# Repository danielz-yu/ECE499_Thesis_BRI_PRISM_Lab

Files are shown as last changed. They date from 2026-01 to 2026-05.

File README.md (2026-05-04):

# ECE499Y Thesis

**Development and Characterization of Textile-Electrode Electroencephalogram Systems for Brain-Computer Interfaces**

The objective of this thesis is to advance the development of a wearable electroencephalography (EEG) system using textile-based electrodes for signal acquisition over hair-covered regions and regions where the skin is exposed directly. The project encompasses both hardware and software development, with a focus on prototyping pre-amplifier circuits for textile electrodes and designing computational methods for processing these recorded textile-based EEG signals.

A pre-amplifier circuit will be prototyped and tested to specifically improve signal acquisition from textile electrodes. Afterwards, digital signal processing methods will be implemented to filter and enhance textile-based EEG signals. Models will be developed to mitigate noise, improve signal-to-noise ratio, and optimize classification performance in brain-computer interface (BCI) applications. The combined hardware and software system’s performance will be characterized and benchmarked against gold-standard clinical EEG electrodes in both simple experimental paradigms and established BCI tasks.

This study aims to demonstrate the technical feasibility of textile-based EEG for wearable BCI applications and its research outcomes are expected to contribute both to academic knowledge and to potential commercialization efforts in collaboration with industry partners. Findings will support the preparation of a publication detailing textile electrode validation, EEG signal amplifier design, and software-based signal filtering, with future applications extending toward wearable BCI systems and clinical use cases.

#

**Research:**
- **Thesis Title:** Development and Characterization of Textile-Electrode Electroencephalogram Systems for 
Brain-Computer Interfaces
- **Supervisors:** Dr. Tom Chau, Dr. Paul Yoo
- **Affiliations:** Bloorview Research Institute, Holland Bloorview Kids Rehabilitation Hospital; Department of Electrical & Computer Engineering, University of Toronto; Institute of Biomedical Engineering, University of Toronto

**Deliverables:**
- ✏️ [Proposal](https://github.com/danielz-yu/ECE499_Thesis_BRI_PRISM_Lab/blob/main/ece499_deliverables/proposal/ECE499%20Thesis%20Proposal%20%7C%20Daniel%20Yu.pdf)
- 📚 [Interim Report](https://github.com/danielz-yu/ECE499_Thesis_BRI_PRISM_Lab/blob/main/ece499_deliverables/interim_report/ECE499%20Interim%20Report%20%7C%20Daniel%20Yu.pdf)
- 📔 [Thesis](https://github.com/danielz-yu/ECE499_Thesis_BRI_PRISM_Lab/blob/main/ece499_deliverables/final_thesis/ECE499%20Final%20Thesis%20Report%20%7C%20Daniel%20Yu.pdf)

#
<br>

<div align="center">
    <a href="https://hollandbloorview.ca/research-education/bloorview-research-institute">
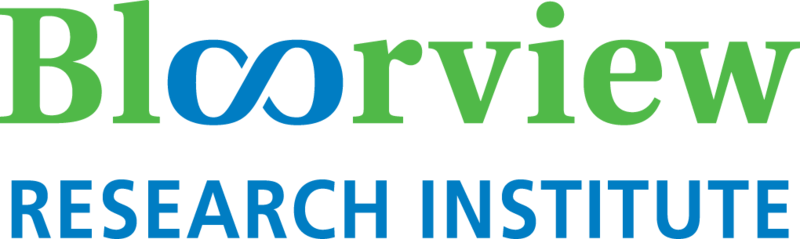
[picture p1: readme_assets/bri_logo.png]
Bloorview Research Institute
        
    </a>
</div>

<br>
<br>
<br>

<div align="center">
    <a href="https://hollandbloorview.ca/">
        Holland Blooriew Kids Rehabilitation Hospital
    </a>
</div>

<br>
<br>

<p align="center">
  <a href="https://www.ece.utoronto.ca/">Department of Electrical & Computer Engineering</a>
  &nbsp;&nbsp;&nbsp;&nbsp;
  <a href="https://bme.utoronto.ca/">Institude of Biomedical Engineering</a>
</p>

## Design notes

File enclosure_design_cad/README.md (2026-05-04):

## Enclosure Design CAD

This folder contains the source and export files used for the active electrode enclosure.

- `3D_printing/` — print-preparation files:
	- `.3mf` file: Editable 3D slicer file. This can be modified when changing which parts to print or print settings before slicing.
	- `.gcode` file: Pre-sliced printer instructions prepared with my printer settings (PLA, Bambu Lab A1).
- `fusion360/` — Native Autodesk Fusion 360 part files:
	- `.f3d` files: Contains full editable single-part designs (retains design history and all features).
	- `.f3z` files: Fusion 360 assemblies (contain multiple parts and references). Assemblies require their referenced part files to open correctly.
- `renders/` — Rendered images showing what the assembled enclosure should look like.
- `step/` — STEP exports for CAD exchange. STEP is more interoperable but still loses parametric feature history compared to native files.
- `stl/` — Exported meshes for 3D printing or simulation. Note: STL is a triangulated mesh and loses feature/history/parametric data from the native CAD.

## Other Notes

- Use the native Fusion 360 `.f3d` files to make design changes or extract precise dimensions. 
- Use STEP only for exchange with other CAD packages or if the CAD software does not import native Fusion 360 files.
- Use STL for quick printing or prototyping, but be aware it is a mesh-only format.
- The `.3mf` in `3D_printing/` is the recommended starting point for preparing prints as it contains part placement and custom print settings.
- The included `.gcode` was sliced for a Bambu Lab A1 with PLA using my printer profile. If you use a different printer or material, re-slice from the `.3mf` (or from an STL exported from the native part) to ensure proper temperatures, speeds, and bed/filament settings.

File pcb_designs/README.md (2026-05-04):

# Printed Circuit Boards (PCB)

This folder contains the KiCad PCB designs for the active electrode prototypes, including custom KiCad component libraries, board schematics and layouts, and production files.

## Custom KiCad Libraries

The `custom_KiCad_components/` folder contains custom-designed symbols, footprints, and 3D models for components used in these PCB designs.

### Adding Custom Libraries to KiCad:

#### 1. Symbol Libraries
Open KiCad Symbol Editor → Preferences → Manage Symbol Libraries → Folder Icon (bottom left corner) → Select the symbols folder at:
```
/{USER_PATH}/custom_KiCad_components/ECE499_Thesis.kicad_sym
```

#### 2. Footprint Libraries
Open KiCad Footprint Editor → Preferences → Manage Footprint Libraries → Folder Icon (bottom left corner) → Select the .pretty folder at:
```
/{USER_PATH}/custom_KiCad_components/ECE499_Thesis.pretty/
```

#### 3. 3D Models
3D models are located in:
```
/{USER_PATH}/custom_KiCad_components/ECE499_Thesis.3dshapes/
```
3D models can be copied to your local computer's KiCad application folder at the `3dmodels` folder and synced to each component manually.

### Important Notes:
- In both the Symbol and Footprint Editors, ensure that custom libraries have **"Active"** and **"Visible"** checkmarks enabled.
  - These are set by default but may need verification if the libraries do not appear.
  - Refresh the editors after enabling to load the new custom components.

## Folder Structure

### `old_designs/`
Contains old, incorrect KiCad PCB designs kept for historical reference only. **Do not use these for production or future work.**

### `OpenEEG-J_Foltynsky/` and `OpenEEG-J_Hansmann/`
Two reference designs based on the [OpenEEG project](https://users.dcc.uchile.cl/~peortega/ae/):
- **J. Foltynsky Design**: OpenEEG variant by Jarek Foltynsky
- **J. Hansmann Design**: OpenEEG variant by Joerg Hansmann

Each folder contains:
- `.kicad_sch` 	— Schematic file
- `.kicad_pcb` 	— PCB layout file
- `.kicad_pro` 	— KiCad project file (main file) 
- `.step` 		— 3D STEP model of the board
- `-backups/` 	— Backup folder for version control
- `production/` — Generated production files (see explanation below)

#### Production Folder
The `production/` subfolder contains files generated using the **KiCad Fabrication Toolkit** (available natively in KiCad Content Manager):
- **Gerber Files** — A zipped file containing all PCB layers and drill holes for board fabrication
- **BOM (Bill of Materials)** — A CSV list of all active and passive components required for direct manufacturer PCB assembly
- **Positions CSV** — XY coordinates and rotation angles of all components required for direct manufacturer PCB assembly

## JLCPCB Ordering Details

These PCB designs are configured for ordering from JLCPCB. Use the following settings:

### Recommended Settings
- **URL**: https://jlcpcb.com/
- **Deburring**: No
  - Deburring is typically only available for very small boards
  - Use "No" for prototype boards (deburring adds time)
  - For final production boards, enable deburring to polish the edges

### PCB Assembly
- **Make sure to double-check the footprint for all components** before submitting.
- **Verify integrated circuit (IC) pin alignment** — Ensure all ICs are oriented with the correct first pin position matching the schematic.

### Upload Files
- Upload the `.zip` Gerber file directly from the `production/` folder
- Upload the BOM and positions CSV for assembly services if needed
- Review and confirm component placement on JLCPCB's interactive preview before finalizing

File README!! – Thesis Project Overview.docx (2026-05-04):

Development and Characterization of Textile-Electrode Electroencephalogram Systems for Brain-Computer Interfaces

The objective of this thesis is to advance the development of a wearable electroencephalography (EEG) system using textile-based electrodes for signal acquisition over hair-covered regions and regions where the skin is exposed directly. The project encompasses both hardware and software development, with a focus on prototyping pre-amplifier circuits for textile electrodes and designing computational methods for processing these recorded textile-based EEG signals.

A pre-amplifier circuit will be prototyped and tested to specifically improve signal acquisition from textile electrodes. Afterwards, digital signal processing methods will be implemented to filter and enhance textile-based EEG signals. Models will be developed to mitigate noise, improve signal-to-noise ratio, and optimize classification performance in brain-computer interface (BCI) applications. The combined hardware and software system’s performance will be characterized and benchmarked against gold-standard clinical EEG electrodes in both simple experimental paradigms and established BCI tasks.

This study aims to demonstrate the technical feasibility of textile-based EEG for wearable BCI applications and its research outcomes are expected to contribute both to academic knowledge and to potential commercialization efforts in collaboration with industry partners. Findings will support the preparation of a publication detailing textile electrode validation, EEG signal amplifier design, and software-based signal filtering, with future applications extending toward wearable BCI systems and clinical use cases.

Folder Structure

- Code/
  - Contains a Python script for XDF processing and plotting, along with coding requirements.
- Data/
  - Recorded raw EEG datasets for analysis.
  - Contains .xdf`sessions and organized by different recording dates and devices.
- Documents/
  - Includes thesis documents and presentation assets.
- Enclosure Design/
  - Mechanical design files for the printed circuit board enclosure.
  - Contains Autodesk Fusion 360 files, various computer-aided design exports, model renders, and 3D printing code.
- Papers/
  - Reference literature and research papers relevant to the textile project.
- Printed Circuit Boards/
  - Hardware design files and manufacturing assets.
  - Contains KiCad projects, custom symbols/footprints/3D models, old design iterations, and production files.
- Results/
  - Plot generated from the XDF analysis script.
  - Organized between testing methodologies for all figures and derived data.

Design Sourcing

Software:

- Mechanical Design
  - Autodesk Fusion 360
  - BambuStudio
- Electrical Design
  - KiCad

Hardware:

- Enclosure Assembly
  - PLA filament printed using a Bambu Lab A1 printer
  - Snap buttons taken from these connectors in the Rapid Prototyping Hub’s electronic cabinet

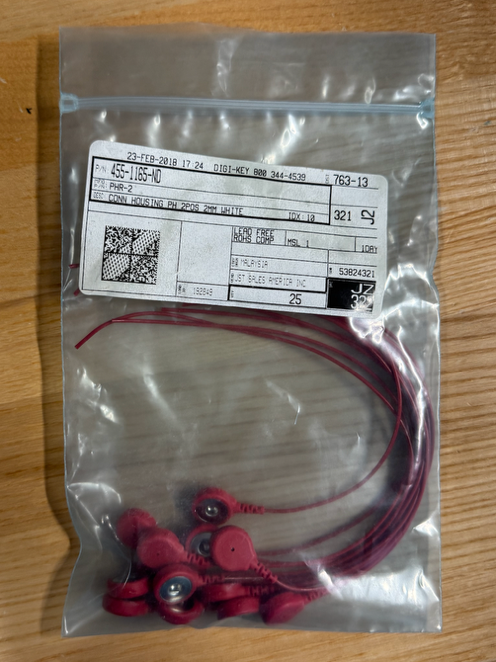
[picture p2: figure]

    - The female snap button needs to be ripped out of this component
- Circuit Testing
  - All electrical components sources from the Rapid Prototyping Hub
    - Specifically used the AD706 operational amplifier
  - Breadboard, oscilloscope, voltmeter, and other testing devices sourced from the Rapid Prototyping Hub
- PCB Design
  - Manufactured using the PCB Assembly option with JLCPCB (https://jlcpcb.com/)
  - Power and signal connections used stranded 32 AWG shielded wires found here:
    - https://www.digikey.ca/en/products/detail/tensility-international-corp/30-01432/13151730
  - Soldering completed at the University of Toronto; can also be completed in the Rapid Prototyping Hub

Contact

- UofT Email: danielz.yu@mail.utoronto.ca
- Personal Email: danielu6776@gmail.com

Feel free to contact me anytime! :)

ECE499Y | ThesisDaniel Yu University of Toronto2025 – 2026

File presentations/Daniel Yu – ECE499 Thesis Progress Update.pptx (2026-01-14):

## ECE499 Thesis Progress Update

Daniel Yu
January 7th, 2026

## Outline

- Problem Statement & Objective
- Methodology
- Preliminary Results
- Next Steps & Timeline

## Problem Statement & Objective

Core Problem:
- To design and validate textile EEG electrodes that can achieve clinically acceptable signal quality while improving usability
Current Limitations:
- Wet EEG systems impractical for pediatric and long-duration use
- Textile and dry electrodes remain insufficiently validated

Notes: Limitations of Pediatric EEG Acquisition
Conventional wet EEG systems are impractical for pediatric and long-duration use due to discomfort from gel, lengthy setup, and sensitivity to motion.
Textile and dry electrodes offer improved wearability, but their signal quality, robustness, and performance over hair remain insufficiently validated.
There is a lack of standardized, repeatable validation frameworks—including anatomically realistic head phantoms—for comparing emerging EEG sensor materials against medical-grade gold standards.
Consequently, the design trade-offs between comfort, manufacturability, and signal fidelity in pediatric EEG systems are not well understood.
Core Problem:
How to design and rigorously validate multichannel pediatric EEG sensors—particularly textile-based electrodes—that achieve clinically acceptable signal quality while improving usability.

Sub-objectives to explore pre-amplifier design

## Methodology

Raised Height (1.1-1.3)
1mm, 2mm, 3mm
Silver Density (2.1-2.3)
1x, 1.5x, 2x
Area Size (3.1-3.3)
0.5cm, 1.0cm, 2.0cm

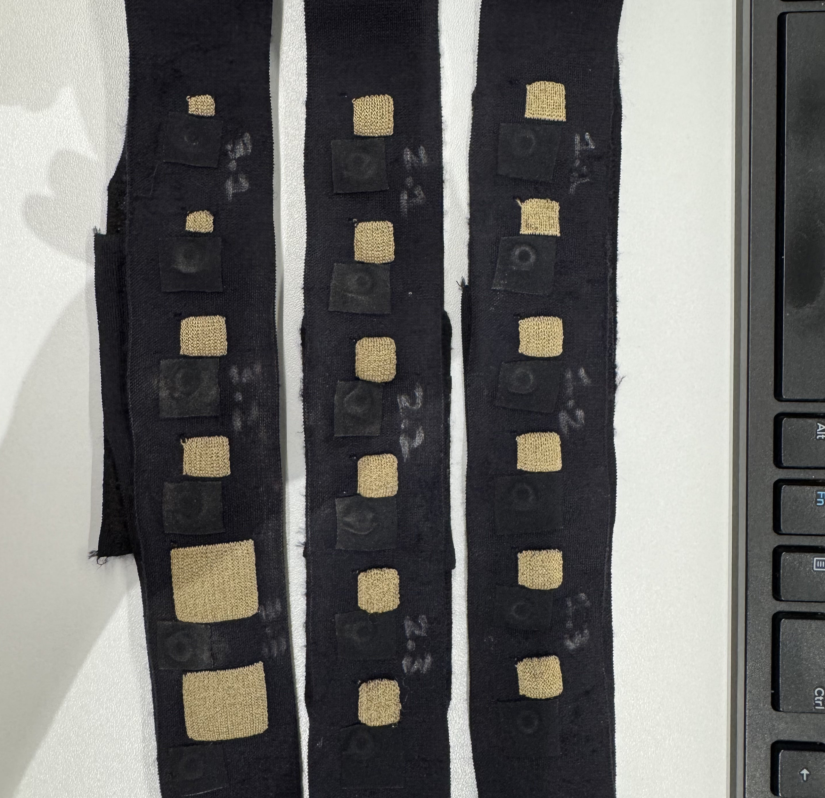
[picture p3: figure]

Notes: - 1.0 --> Raised Height (1x density)
- 1.1: 1 mm
- 1.2: 2 mm
- 1.3: 3 mm
- 2.0 --> Silver Density (2mm height)
- 2.1: least dense (1x)
- 2.2: moderately dense (1.5x)
- 2.3: most dense (2x)
- 3.0 --> Area Size (1x density, 2mm height)
- 3.1: ~0.5 x 0.5 cm
- 3.2: ~1.0 x 1.0 cm
- 3.3: ~2.0 x 2.0 cm
- Notes:
- All pad sizes are approximately 1.0 x 1.0 cm if not specified
- Need more precise quantitative measurables

## Methodology

- Comparison between dry BrainProduct electrodes and textiles electrodes at Fp1 and Fp2 positions
- EEG data acquired using LiveAmp, Lab Recorder, and Mindset

Blink Test:
Movement artifacts
~200 seconds x 10 times
2 seconds per blink
Eyes Open/Closed:
Alpha band
10 seconds open/closed x 10 times

## Preliminary Results

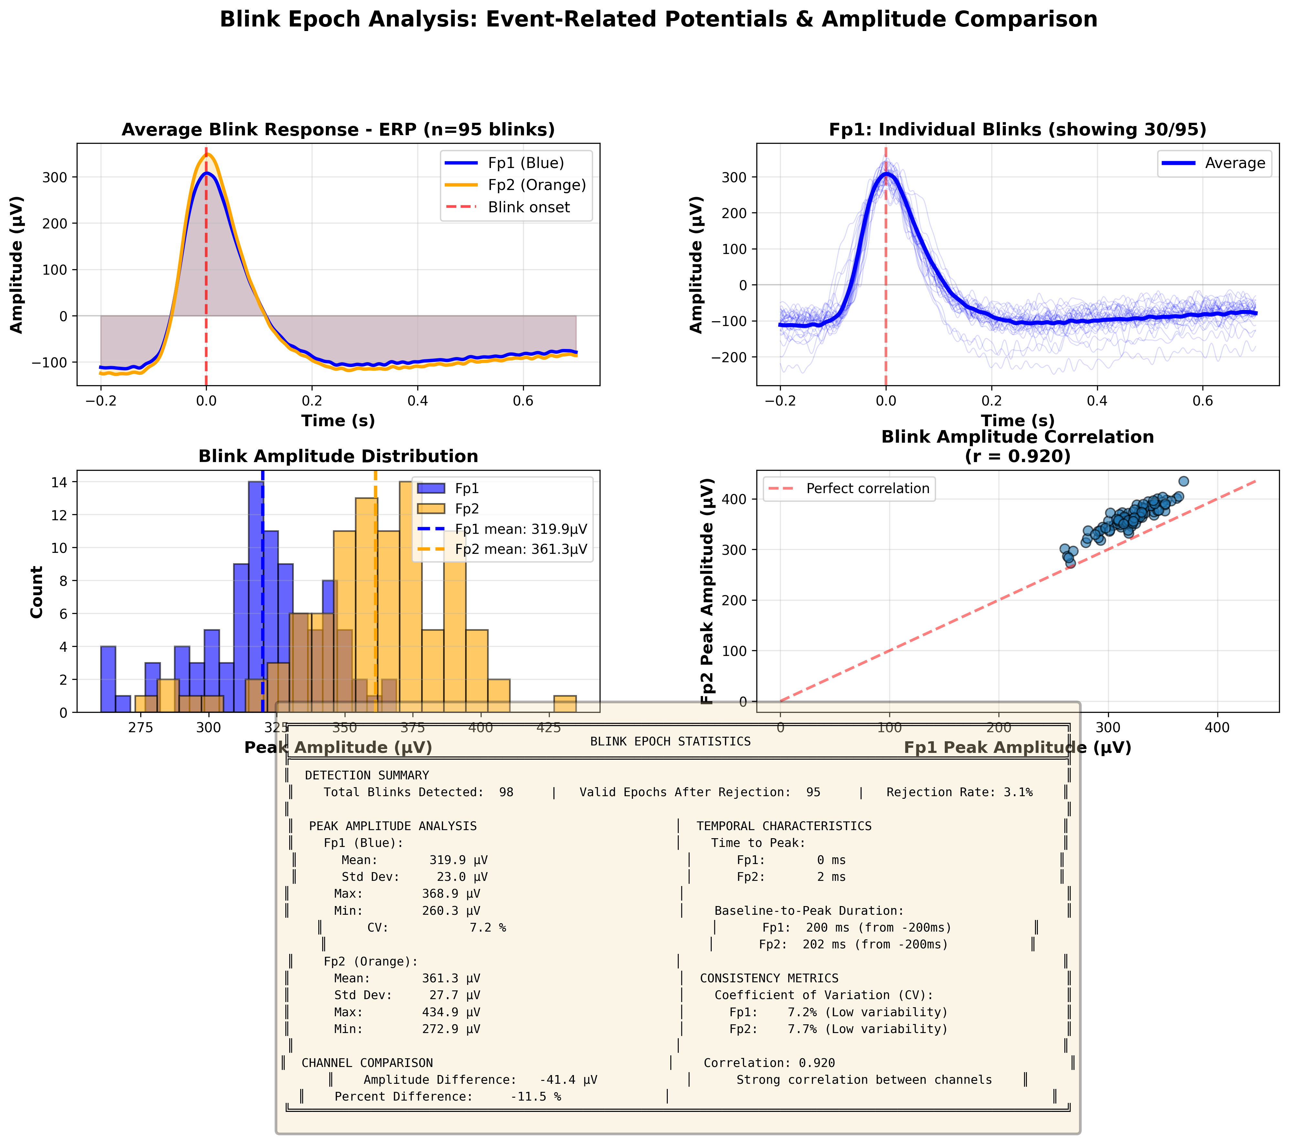
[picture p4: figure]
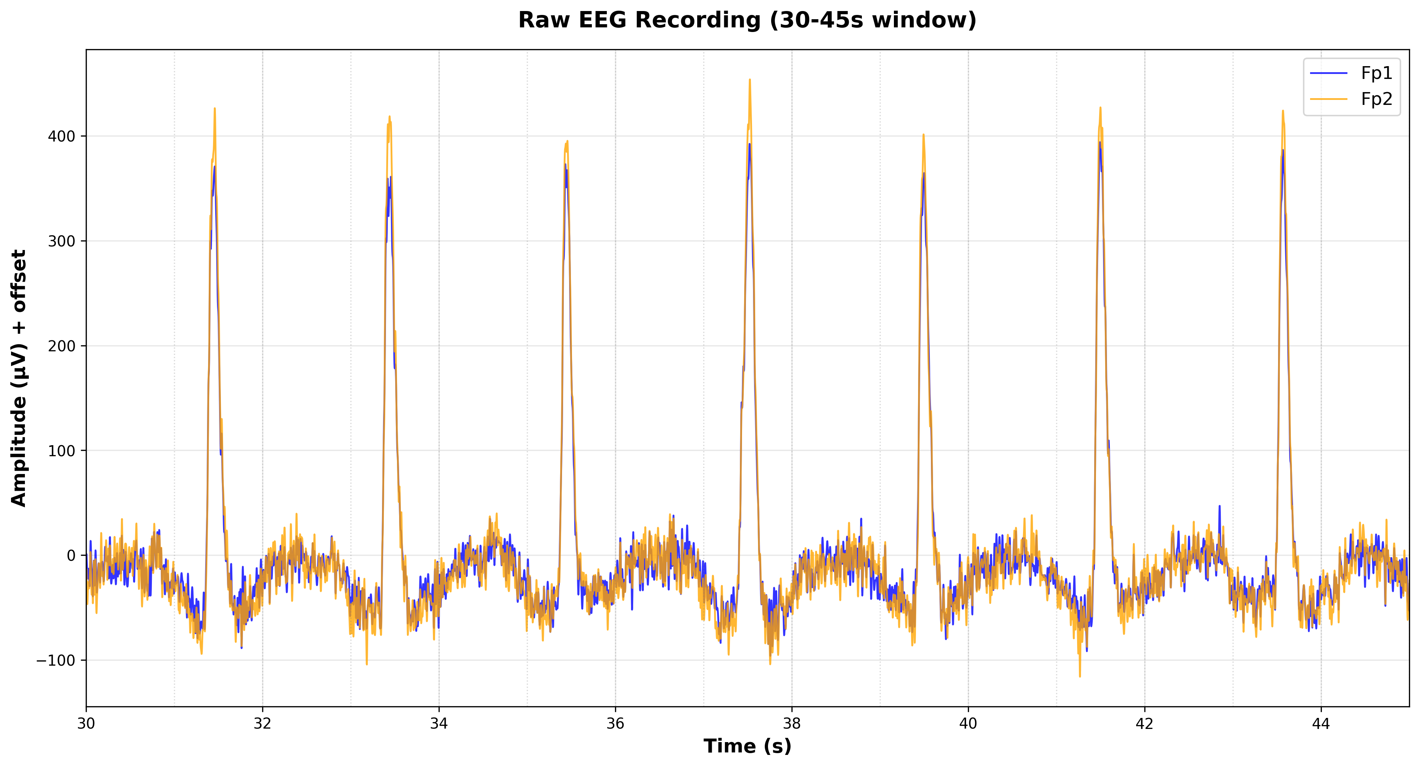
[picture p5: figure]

## Preliminary Results

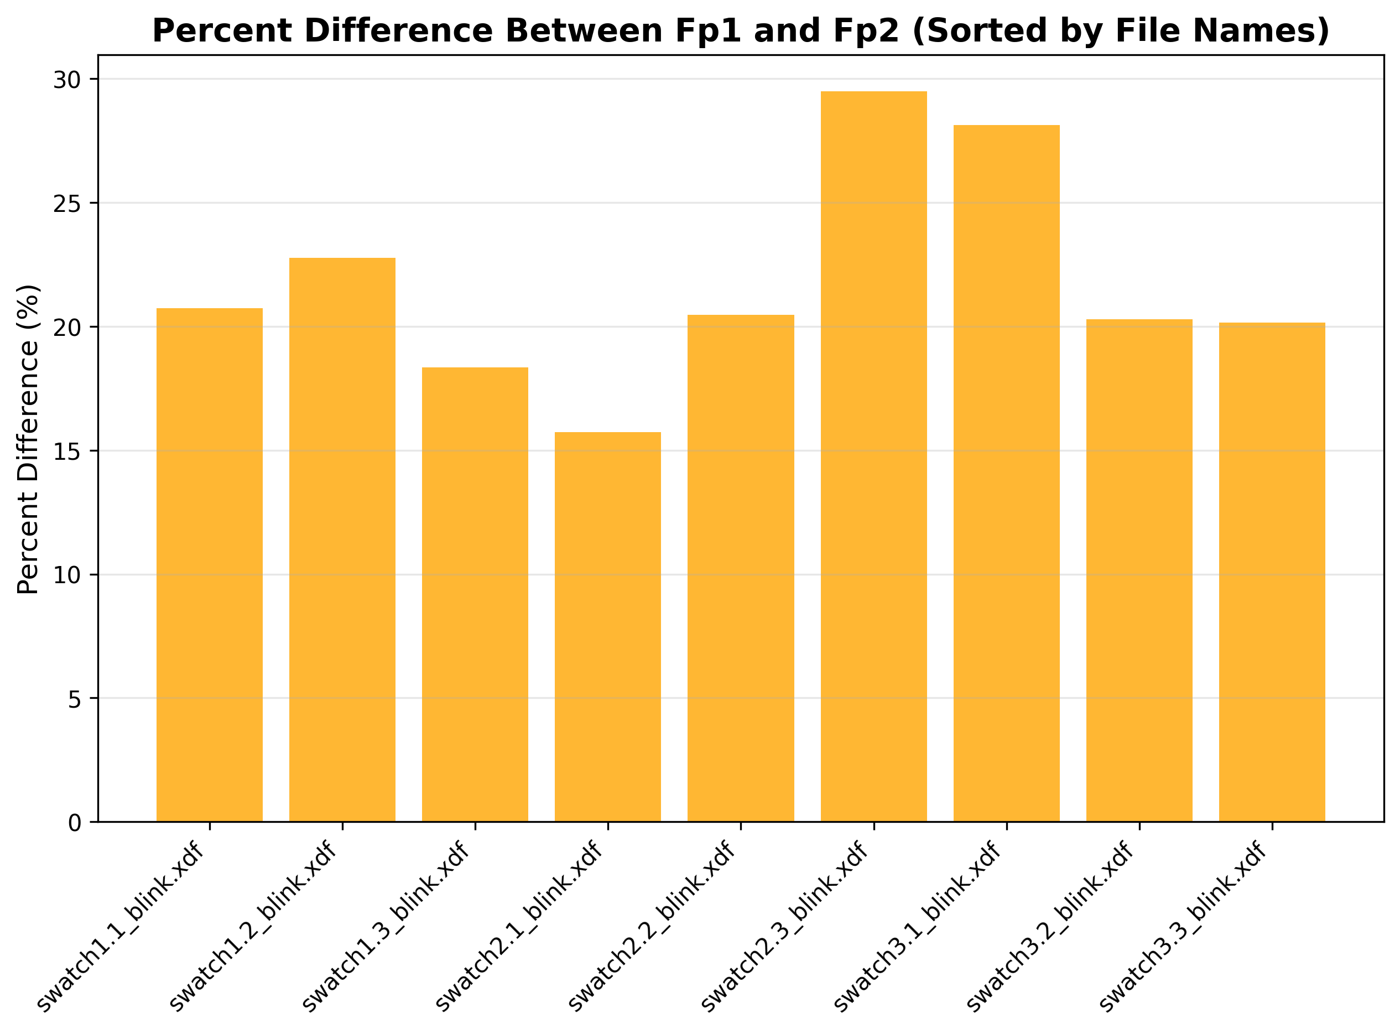
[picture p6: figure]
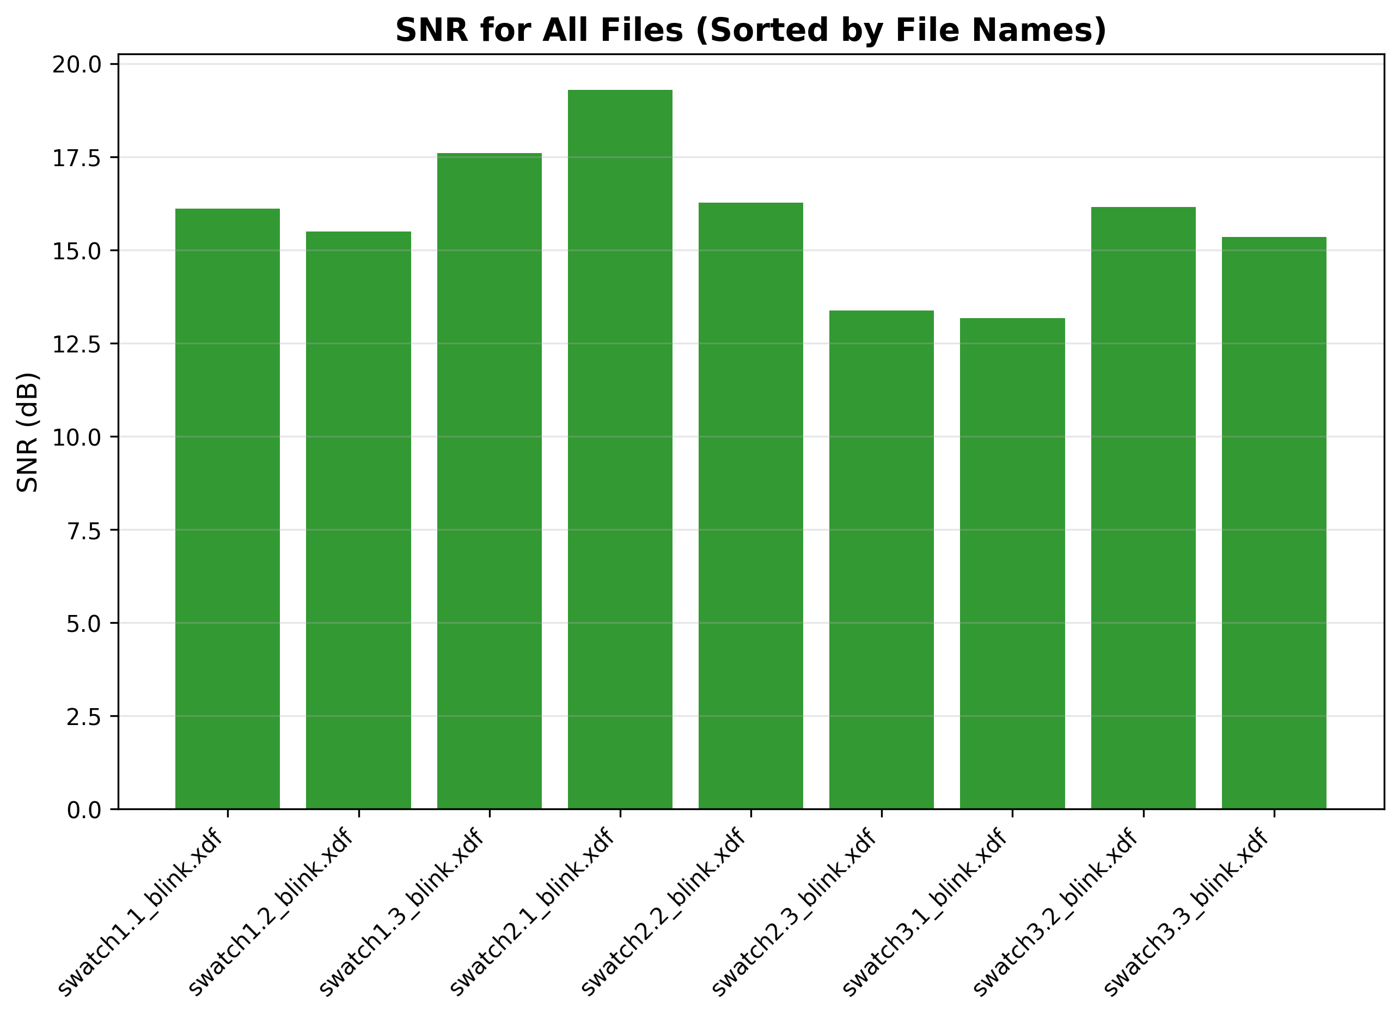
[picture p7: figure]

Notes: Takes the entire raw EEG signal for each channel
Calculates the Root Mean Square (RMS): √(mean of squared values)
Converts from Volts to microvolts (×10⁶)
This represents the total signal power across all frequencies
Applies a high-pass filter at 30 Hz to isolate high-frequency content
The rationale: EEG signals of interest (Delta, Theta, Alpha, Beta) are typically below 30 Hz
Content above 30 Hz is assumed to be primarily muscle artifacts, electrical noise, and environmental interference
Calculates RMS of this filtered signal as the noise floor estimate

## Preliminary Results

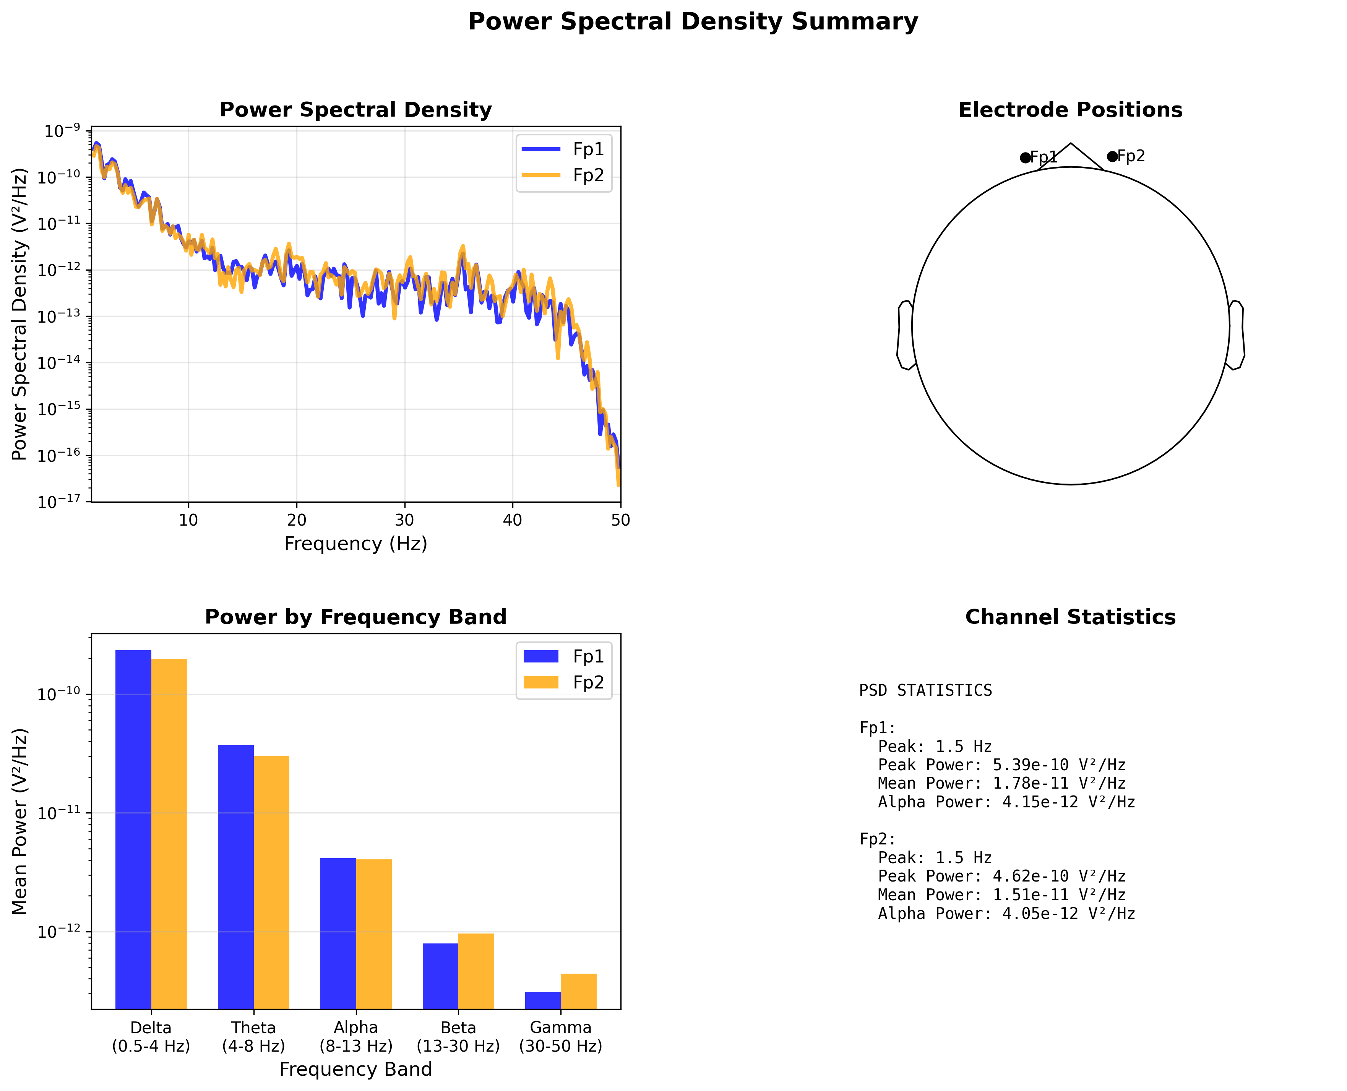
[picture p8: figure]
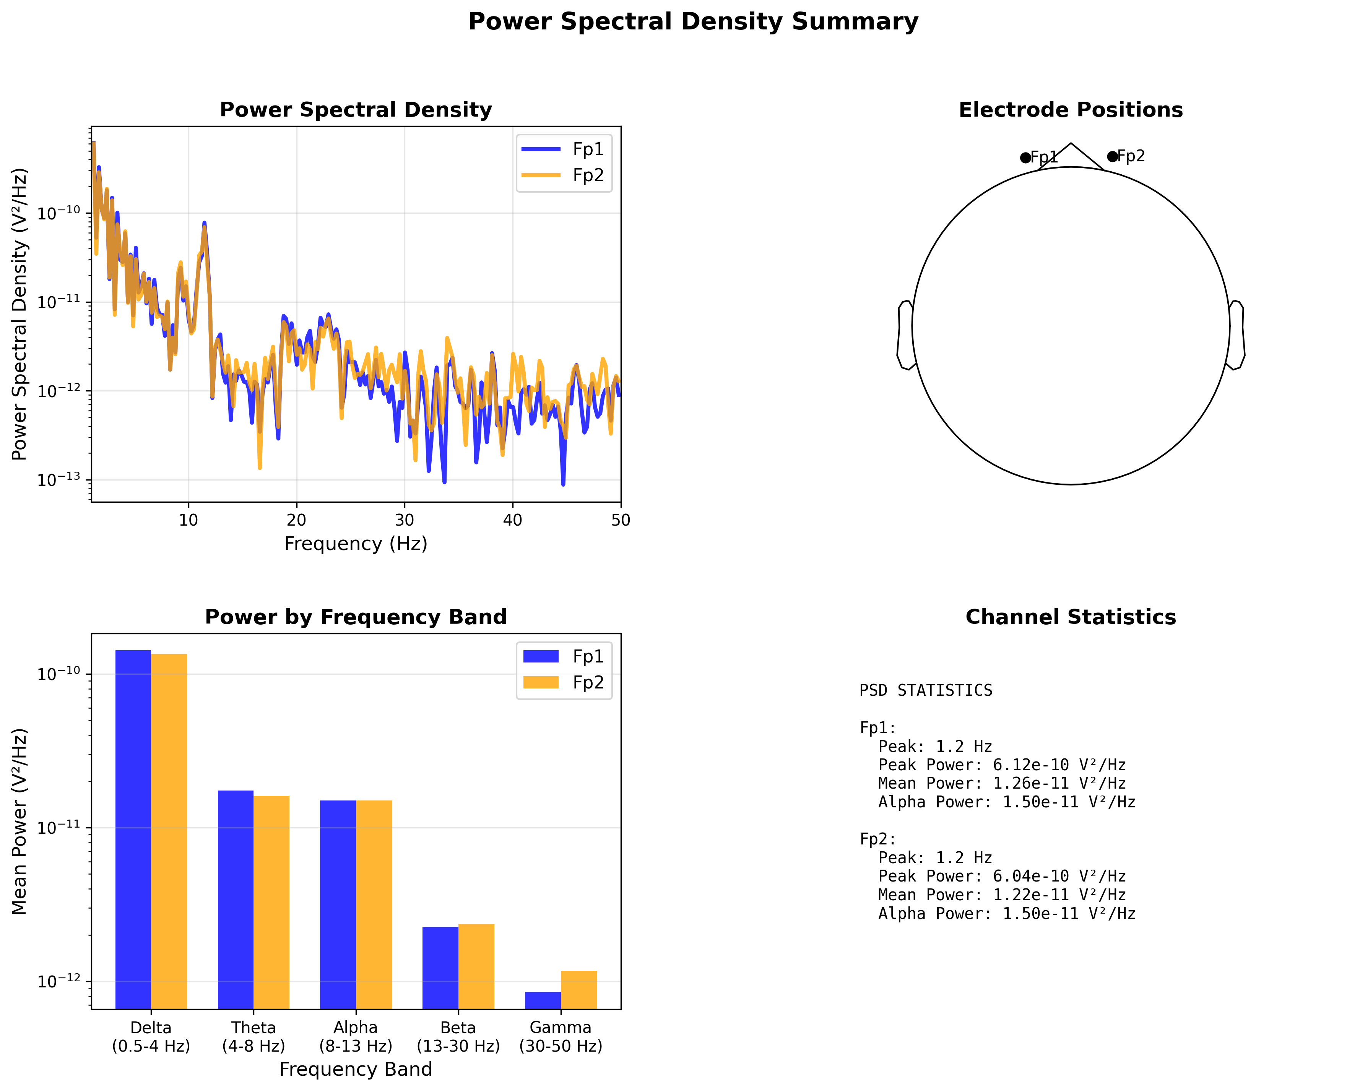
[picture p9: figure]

## Next Steps

- Pre-amplifier design
  - High-input impedance: 10^12 Ohms
  - Configurable gain: Set using SMD resistor
  - Band-pass filter: Set using SMD resistors for high-pass/low-pass cutoffs
  - Common-mode noise rejection
  - Operating voltage around 3.3-5V
  - Requires ADC (ADS1299x)

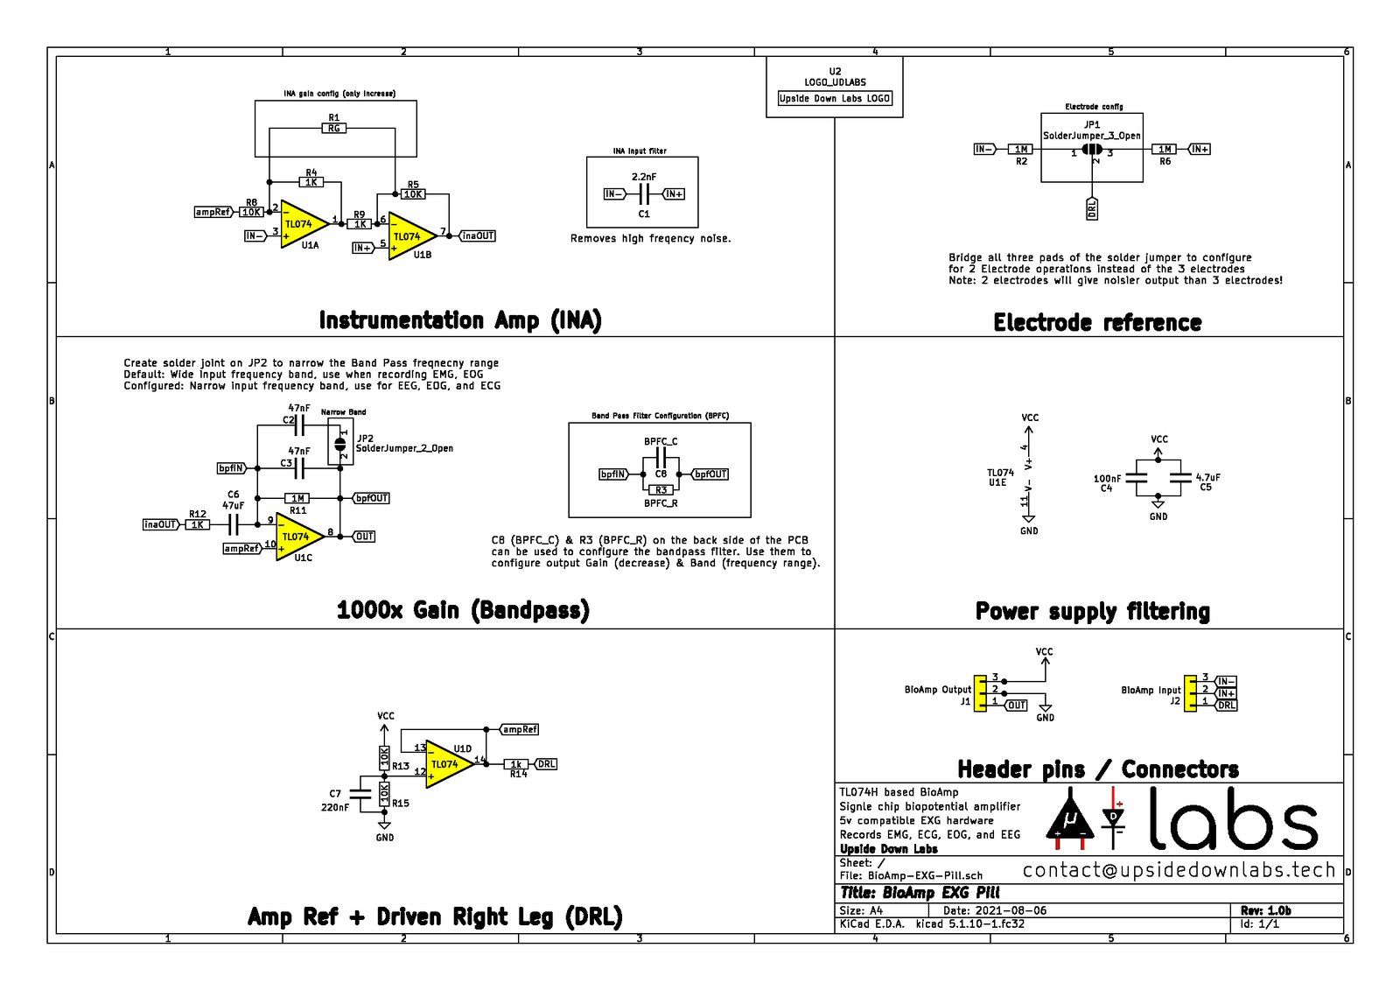
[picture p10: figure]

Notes: BioAmp EXG Pill
Open Source: Both hardware and example software freely available.
Core Amplifier and Front-End Characteristics
While the detailed schematic is in the open-source files, the BioAmp EXG Pill embeds a biopotential instrumentation amplifier and configurable filtering components which are typical of EEG preamplifier design:
Input and Conditioning
High input impedance: ~10^12 Ω, which is critical to avoid loading the microvolt-level EEG signals. Upside Down Labs Docs
Electrode configuration: Supports standard 3-electrode differential measurements (active, reference, ground). Upside Down Labs Docs
Bias and reference options: Electrode pads can be bridged to support 2-electrode modes (less ideal for EEG due to reference issues). Upside Down Labs Docs
High input impedance and differential measurement are foundational to minimizing signal attenuation and common-mode artifact pickup in EEG preamplifiers.
Gain and Filtering
Configurable gain: Set by surface-mount resistor (R6) choice on the instrumentation amplifier. Upside Down Labs Docs
Band-pass filter: Configurable with discrete components (e.g., R12, C5) to tailor high-pass and low-pass cutoffs. Upside Down Labs Docs
Default configuration is optimized for EEG/EOG frequency ranges (~0.5–30 Hz). Crowd Supply
Users can modify filter components to shift band limits if targeting other biopotentials (EMG, ECG). Upside Down Labs Docs
Noise rejection: Designed to reject mains and environmental noise through hardware filtering and amplifier design. Crowd Supply
This structure reflects a typical first amplification stage plus a band-limited pass that centers the EEG frequency content while attenuating out-of-band noise before digitization.

## Timeline

- Interim Report – January 12th
- Pre-amplifier component selection/testing – End of January/Start of February
- Testing with prototype board against wet electrode system – Mid February/March
- Thesis/Presentation – April

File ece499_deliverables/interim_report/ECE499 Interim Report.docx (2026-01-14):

Development and Characterization of Textile-Electrode Electroencephalogram Systems for Brain-Computer Interfaces

Daniel Yu

1007678461

January 12th, 2026

Supervisors: Dr. Tom Chau, Dr. Paul Yoo

ECE499Y Thesis | Interim Report

List of Tables

# 1.0 Introduction

Electroencephalogram (EEG) systems have become essential tools in both clinical diagnostics and research application, particularly in the field of brain-computer interfaces (BCIs). Conventional EEG systems rely on wet electrodes that require conductive gel to establish electrical contact between the scalp and sensing hardware. While these systems deliver high signal quality suitable for various clinical and research purposes, they present practical limitation as its application of conductive gel is time-consuming, uncomfortable for users, and may cause skin irritation when worn for extended periods. These constraints make traditional wet electrode systems impractical for pediatric population in rehab and long-duration monitoring clinical or research cases.

In recent years, there has been growing interest in developing wearable EEG collection devices that address these usability challenges. Textile-based electrodes have emerged as a promising alternative as its simple integration into fabrics offers improved comfort and flexibility. Unlike wet electrodes, textile electrodes can be incorporated directly into wearable garments or headbands in a dry format without the need for conductive gel. This technological shift has the potential to expand EEG accessibility beyond traditional clinical settings into community and home environments. However, a significant technical challenge persists as textile-based electrodes have not yet proven to achieve signal quality comparable to clinical and research-grade wet electrodes. The primary limitation stems from high impedance at the electrode-skin interface, particularly over hair-covered regions of the scalp where establishing consistent electrical contact is inherently difficult. This impedance mismatch introduces increased noise, reduced signal amplitude, and greater susceptibility to motion artifacts, all of which compromise the reliability of recorded EEG signals. For textile electrodes to become viable alternatives in clinical and BCI applications, these signal quality limitations must be systematically addressed through coordinated advances in both hardware design and signal processing methodologies.

The objective of this thesis is to advance the development of a wearable EEG systems using textile-based electrodes for signal acquisition over both hair-covered regions and areas where skin is directly exposed. By addressing both the pre-amplifier circuit design and digital signal processing techniques, this research aims to maximize the signal-to-noise ratio and classification accuracy of textile-based EEG recordings, ultimately achieving performance comparable to standard clinical systems. The combined hardware-software system developed through this work will be characterized and benchmarked against gold-standard clinical EEG electrodes using both motion artifacts detection and fundamental experimental paradigms (such as eyes-open/eyes-closed protocols). Performance will be evaluated across measurement sites on both hair-covered and bare-skin regions to comprehensively assess the system's practical applicability.

The significance of this research extends beyond immediate technical contributions as demonstrating the feasibility of textile-based EEG for wearable BCI applications addresses a critical gap in pediatric neurotechnology that conventional wet electrode systems cannot. Success in this work would enable more accessible, comfortable, and practical EEG monitoring solutions for children, supporting both clinical care delivery and research participation. Furthermore, the research outcomes are expected to contribute to both academic knowledge through publications and potential commercialization efforts with industry partners. Finally, the findings will support the preparation of manuscripts detailing textile electrode validation, EEG signal pre-amplifier design, and software-based signal filtering techniques, with applications extending toward next-generation wearable BCI systems and expanded clinical use cases in pediatric populations.

# 2.0 Literature Review

The development of textile-based electrodes for biopotential signal monitoring has emerged as a promising research direction in wearable health monitoring systems. Several groups have conducted comprehensive reviews demonstrating that textile electrodes can achieve acceptable signal quality for various biopotential measurements when properly designed and implemented [1, 2, 3]. Research comparing textile electrodes to standard clinical electrodes has yielded promising but varied results depending on measurement location and electrode design. Liu et al. investigated textile dry contact electrodes during physical activity, finding that correlation between EEG signals from wet and textile electrodes reached 95.6% under motion conditions, demonstrating near-equivalent signal capture capability [4]. However, textile electrodes face particular challenges when measuring over hair-covered regions of the scalp as studies have consistently shown that hair-covered areas present significantly higher impedance, reducing signal quality compared to hairless regions such as the forehead [4, 5].

Additionally, the amplification of biopotential signals presents unique technical challenges that distinguish these systems from general-purpose amplifiers. Biopotential amplifiers must satisfy several critical requirements such as the need for ultra-high input impedance to minimize signal loading, high common-mode rejection ratio (CMRR) to suppress noise, appropriate bandwidth for the signals of interest, sufficient gain to amplify microvolt-level signals, and protection circuits to ensure patient safety [6, 7].

The impedance characteristics of textile electrodes differ substantially from wet electrodes. López-Larraz et al. noted that while standard wet EEG electrodes typically exhibit impedances below 5 kΩ, textile and other dry sensors operate in the range of hundreds of kΩ, resulting in inherently higher noise levels [8]. This fundamental impedance difference necessitates specialized amplifier designs with ultra-high input impedance to prevent signal loading and distortion [6]. Rahman et al. demonstrated that skin impedance should ideally be maintained between 5-20 kΩ for accurate EEG signal generation, though this target becomes challenging to achieve with dry textile electrodes, particularly under dry skin conditions [9].

CMRR is equally critical for EEG amplifier design as it quantifies an amplifier's ability to reject signals common to both inputs while amplifying differential signals. This is an essential capability given that EEG signals, typically measured in microvolts are mixed with larger common-mode interference from sources such as power line coupling and muscle artifacts [10]. High-performance instrumentation amplifiers for biopotential measurement typically achieve CMRR values exceeding 110 dB across the frequency range of interest [11]. The three-amplifier instrumentation amplifier topology has become standard in biopotential applications, providing both high input impedance through buffer amplifiers and excellent CMRR through differential amplification stages [12, 13].

EEG signals span from approximately 0.5 Hz to 100 Hz, with most clinically relevant information contained below 40 Hz [14]. This means that bandwidth and filtering requirements must be carefully matched to the EEG frequency content of interest as limiting bandwidth to this range not only preserves signal fidelity but also optimizes signal-to-noise ratio by rejecting out-of-band interference. Typical implementations include high-pass filters above 0.5 Hz to remove DC offset and electrode polarization effects, and low-pass filters below 100 Hz to prevent aliasing and reduce high-frequency noise [14]. The transition between passband and stopband must be sufficiently gradual to avoid phase distortion that could compromise temporal relationships in the signal.

Altogether, active electrode designs where amplification occurs immediately at the electrode site, have gained prominence in dry electrode EEG systems [6]. This approach offers multiple advantages as the amplified signal is less susceptible to cable motion artifacts, the ultra-high input impedance at the electrode prevents impedance mismatch effects, and the low output impedance of the active electrode drives subsequent amplification stages efficiently [6].

# 3.0 Progress to Date

Building upon the theoretical foundation establish in the literature review, the initial phase of this work constituted experimental data collection and characterization of textile-based electrode signal quality from September to December 2025. This part of the research aimed to establish baseline performance metrics for various textile electrode design parameter and validate their signal quality against gold-standard clinical EEG systems.

## 3.1 Data Collection

The experimental protocol was designed to systematically evaluate textile electrode performance across multiple design parameters while maintaining controlled comparison with established dry electrode technology. Nine types of textile electrodes that were sewn onto three fabric headbands were tested with each headband varying across three primary design dimensions described in the Table 1 and shown in the same order in Figure 1. All textile electrodes are approximately 1.0 cm x 1.0 cm if not specified. More detailed images of can be seen in Appendix A.

Table 1. All nine tested textile electrode configurations following the order shown in Figure 1.

Raised Height | Electrode 1.1 1 mm | Electrode 1.2 2 mm | Electrode 1.3 3 mm
Silver Density | Electrode 2.1 Least dense (1.0x) | Electrode 2.2 Moderately dense (1.5x) | Electrode 2.3 Most dense (2.0x)
Area Size | Electrode 3.1 0.5 cm x 0.5 cm | Electrode 3.2 2.0 cm x 2.0 cm | Electrode 3.3 1.0 cm x 1.0 cm

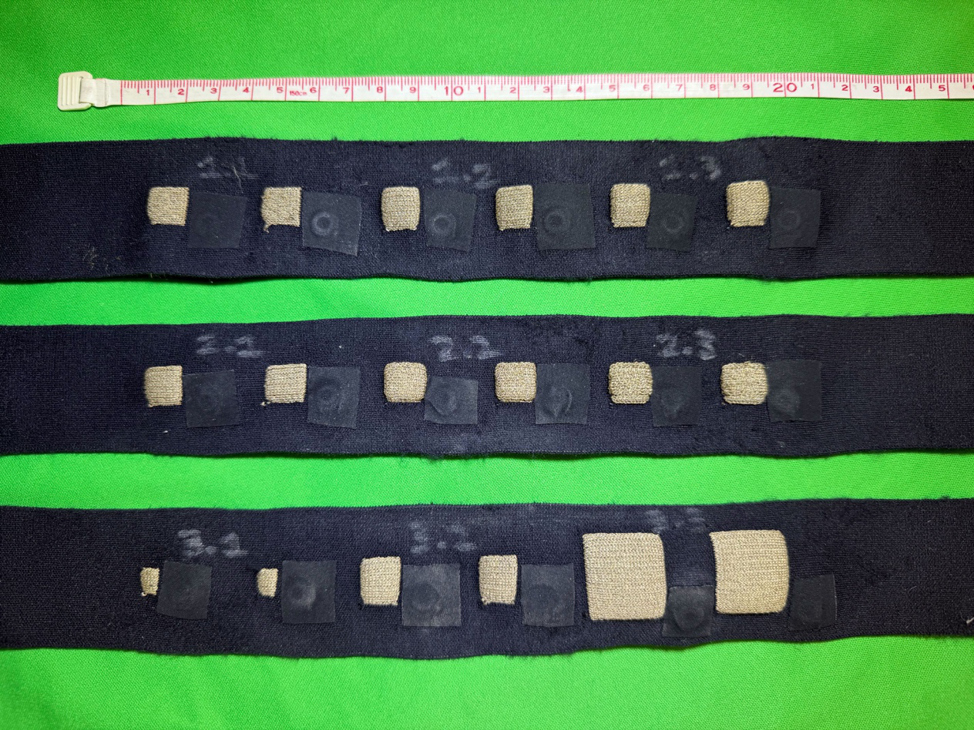
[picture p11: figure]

Figure 1. Three fabric headbands with two textile electrodes of each configuration sewn onto it, totalling 18 total textile electrodes.

The data acquisition utilized the BrainProducts LiveAmp system in conjunction with Lab Recorder and Mindset software, enabling synchronized multichannel EEG recording with precise timing control. The experimental setup positioned textile electrodes at Fp1 and the gold-standard clinical BrainProducts electrodes without the use of gel at the Fp2 location according to the international 10-20 system. Both electrodes used the BrainProducts pre-amplifier circuit connected by a snap button with ground and reference electrodes placed beside each other behind the left ear. The forehead placement was strategically chosen as it represents a hairless region with relatively low impedance, allowing initial validation of textile electrode performance under favorable conditions before progressing to more challenging hair-covered sites.

Two complementary experiments were implemented to assess different aspects of electrode performance. The blink test protocol required me to perform deliberate eye blinks at approximately two-second intervals over a 200-second recording session for each of the nine electrode configurations. This test specifically targets motion artifact characterization, as eye blinks generate large-amplitude, artifacts propagating across frontal electrodes. The consistent morphology and timing of blink artifacts provides a quantifiable metric for comparing artifact amplitude, waveform fidelity, and signal-to-noise characteristics between textile and commercial electrodes.

The second experiment was a eyes-open/eyes-closed test that assessed the electrodes' ability to capture physiologically relevant neural oscillations, specifically focusing on alpha band (8-13 Hz) modulation. This protocol required me to alternate between 10-second eyes-open and 10-second eyes-closed recordings, repeated ten times per electrode configuration. Alpha synchronization during eyes closure from a reduced visual processing demand and cortical idling provides a strong benchmark for evaluating electrode sensitivity to frequency-specific neural activity.

## 3.2 Data Analysis

Preliminary analysis of blink-induced motion artifacts revealed clear, systematic differences between textile and commercial dry EEG electrodes, driven primarily by electrode–skin contact mechanics. Blink artifacts appeared as large, bilaterally symmetric deflections in both Fp1 and Fp2 as seen in Figure 2, often reaching several hundred microvolts, making them a sensitive indicator of contact quality and impedance.

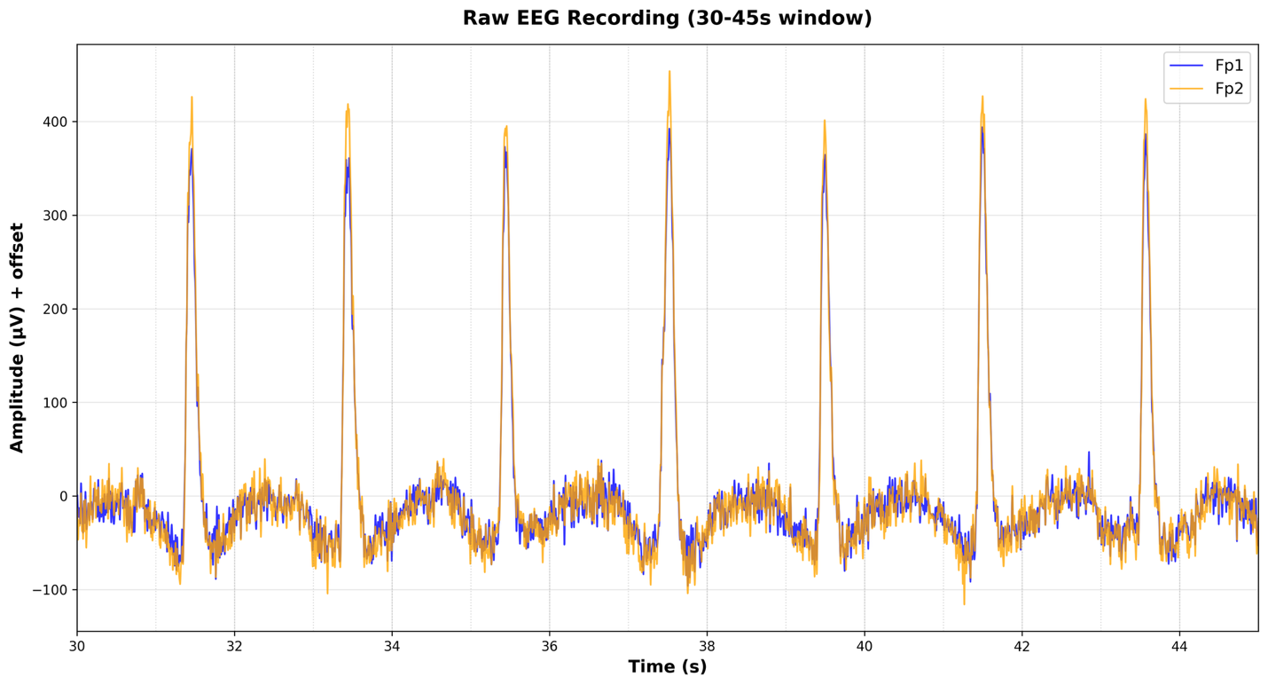
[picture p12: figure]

Figure 2. Raw EEG recording from the 30-45 second window for Electrode 1.1 (raised height of 1 mm).

Figure 3 show the exact difference between textile electrodes and the gold-standard ones on event-related potentials across all blinks. This figure shows the performance of Electrode 1.1 (raised height of 1 mm) on the Fp1 position shown in blue compared against the performance of the gold-standard electrode shown in orange at Fp2. At the average peak amplitude, there is approximately an 11.5% percent difference, or around 41.4 µV between their detection peaks on average.

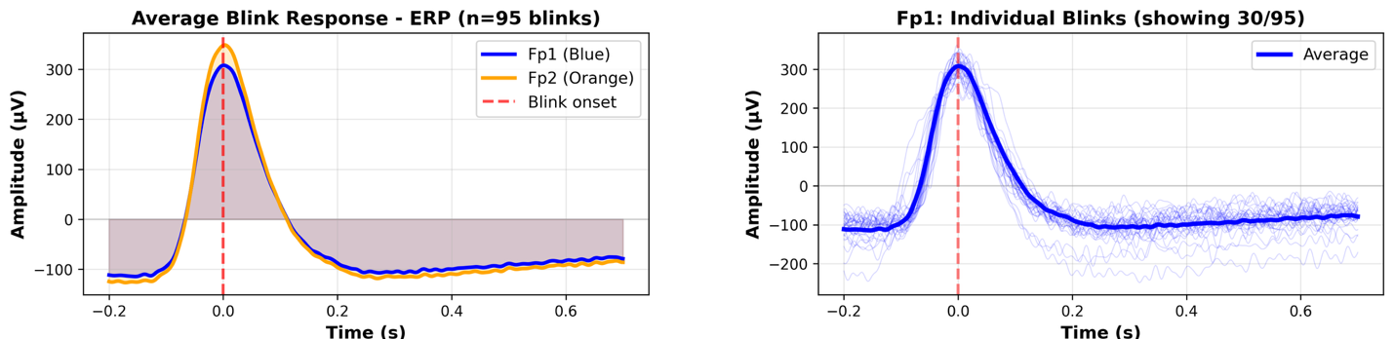
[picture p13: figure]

Figure 3. Event related potentials and average amplitude in microvolts for all recorded blinks during the recording of Electrode 1.1 (raised height of 1 mm).

Within the textile designs, electrode height had the strongest effect as 2–3 mm raised electrodes produced artifact amplitudes and temporal profiles closely matching those of the gold-standard dry electrodes, whereas 1 mm electrodes showed attenuated responses, consistent with inadequate contact pressure during facial muscle motion. These observations support the general expectations that increased electrode height improves penetration through superficial skin layers and stabilizes the interface. Higher silver density reduced baseline noise and improved stability between blink events, though its impact on artifact amplitude was weaker than that of height, indicating that mechanical contact dominates artifact formation. Electrode area affected both amplitude and drift: larger areas captured stronger blink artifacts but were more prone to baseline instability, while a 1.0 cm area offered a practical compromise. Full event related potential analysis can be seen in Appendix B.

Overall, this is summarized in Figure 4 as a percent difference of the microvolts detected between the current tested textile electrode and the gold-standard one. Furthermore, the signal-to-noise ratio (SNR) was calculated and summarized in Figure 5, by comparing root mean square of the overall signal strength against the high-frequency noise levels above 30 Hz for each textile electrode, and its results match the percent difference in Figure 4 in a nearly inversely proportional manner.

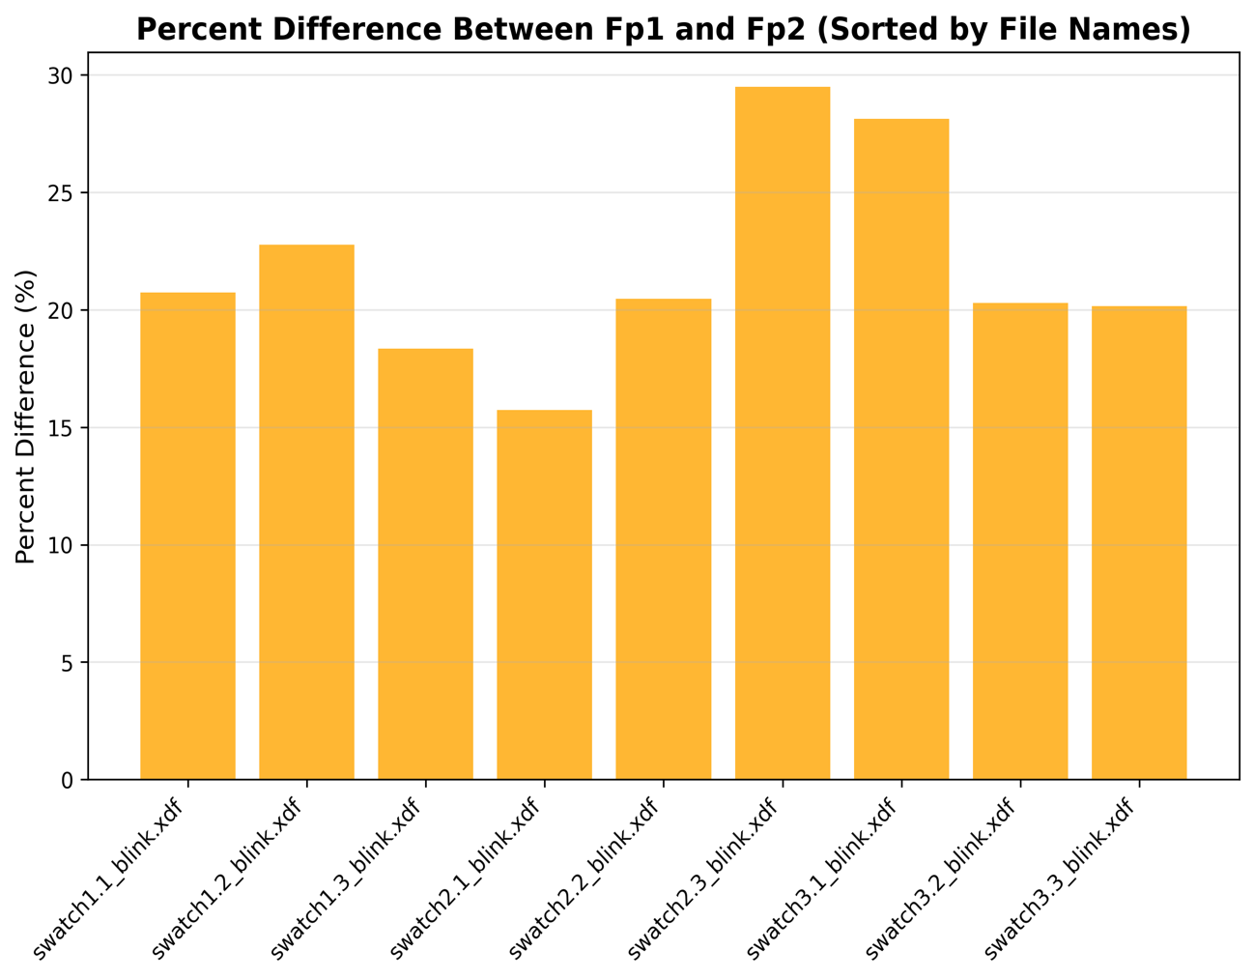
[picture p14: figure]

Figure 4. Percent difference on the measured microvolts across all nine textile electrodes.

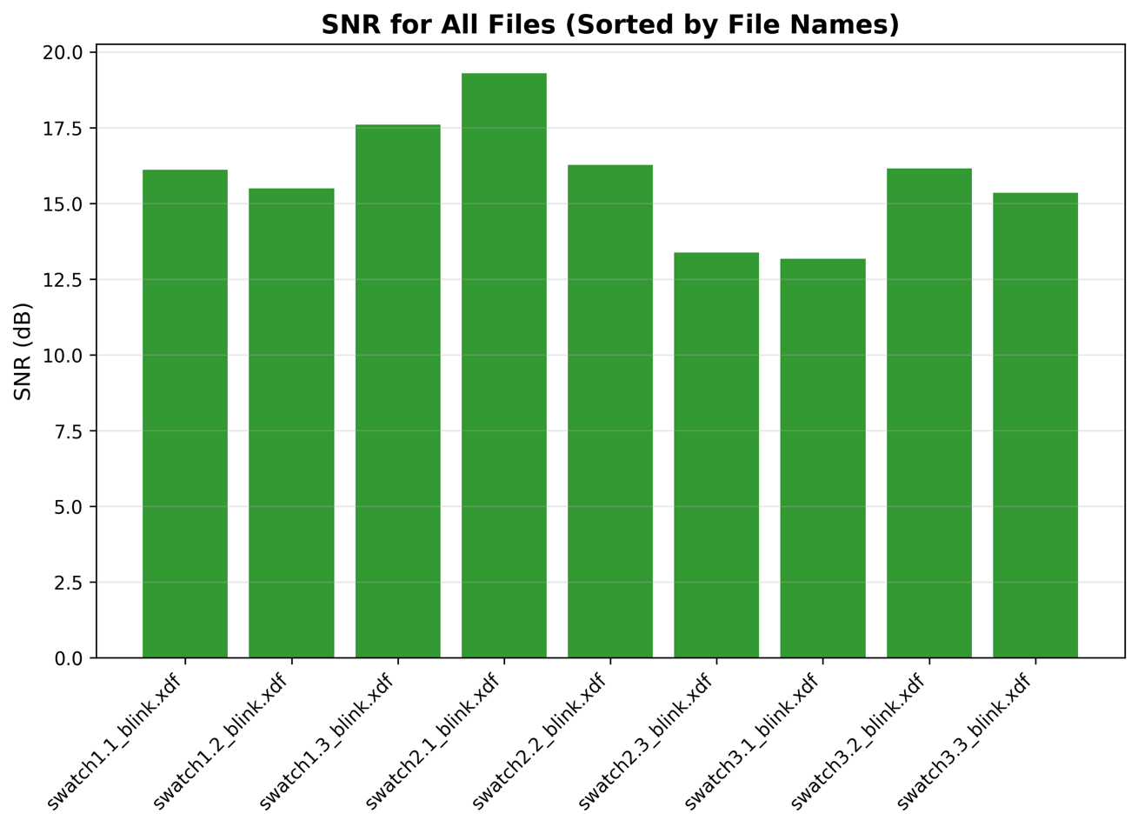
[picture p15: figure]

Figure 5. Signal-to-noise ratio on across all nine textile electrodes.

For the eyes-open/eyes-closed experiment, initial power spectral density (PSD) analysis showed that textile electrodes reliably captured physiologically meaningful alpha activity, with increased 8–13 Hz power during eyes-closed conditions across all configurations as seen in comparison of Figure 6 and 7. While textile electrodes reproduced correct alpha peak frequencies and temporal modulation, they exhibited broader spectra, slightly slower transition dynamics, and lower correlations with the gold-standard electrodes, indicating a slightly reduced but still robust fidelity in detecting neural oscillations.

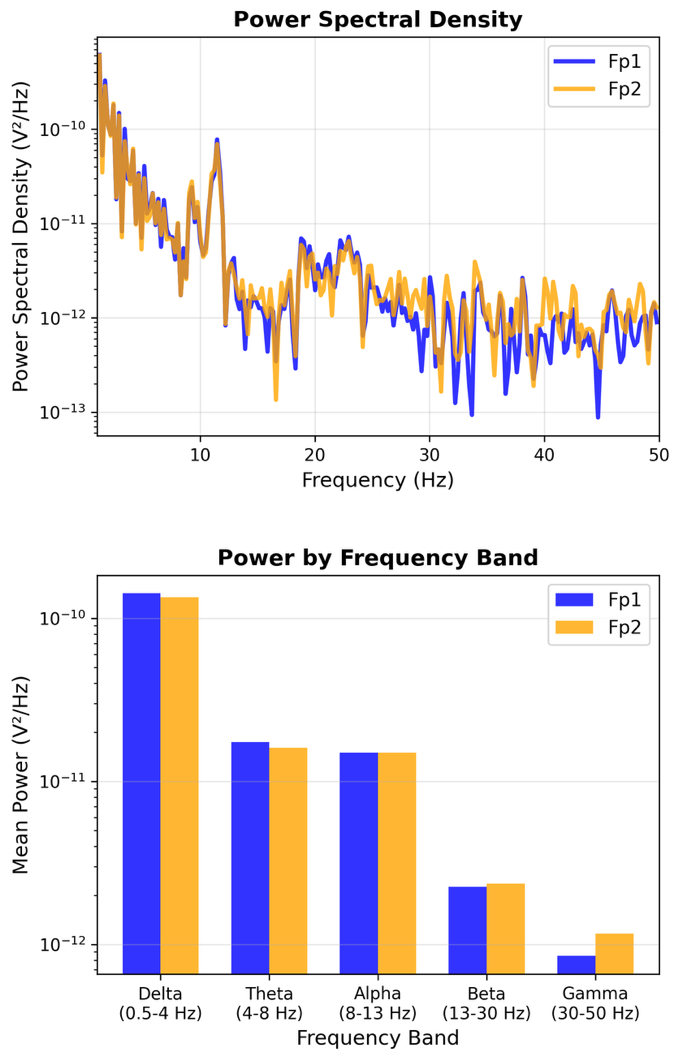
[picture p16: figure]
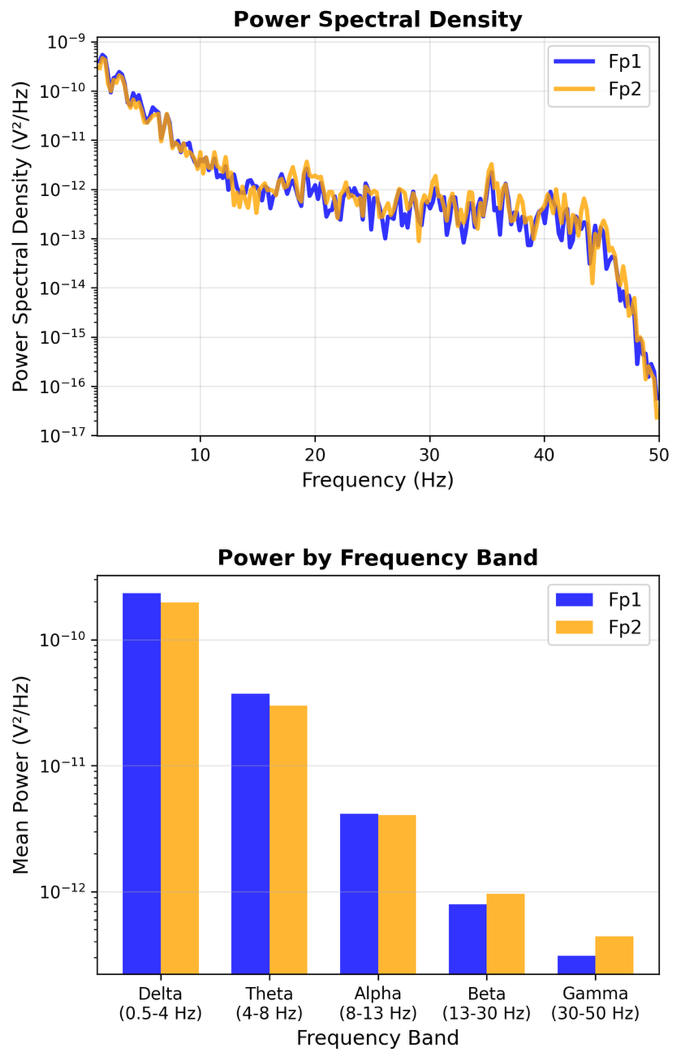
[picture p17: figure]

Figure 6. PSD plot showing higher Alpha band activity during eyes closed experiments on Electrode 1.1 (raised height of 1 mm). | Figure 7. PSD plot showing lower Alpha band activity during eyes open experiments on Electrode 1.1 (raised height of 1 mm)

## 3.4 Limitations

Several experimental limitations must be acknowledged in the interpretations and characterization of the results. The method in which the textile electrode were attached lacked precise control over contact pressure, as textile electrodes were manually positioned and secured with fabric headbands rather than standardized fixtures. Variations in headband tension across trials likely introduced inconsistencies in electrode-skin contact pressure, potentially contributing to performance variability beyond inherent electrode design differences. This limitation particularly affects interpretation of raised height comparisons, where contact pressure directly influences effective skin penetration depth.

Manufacturing variability in the sewn textile electrode patches represents another source of uncertainty. Minor variations in thread tension, stitch density, and conductive material distribution may result in inconsistencies that partially obscure the different design parameter effects, particularly for the silver density variations where fabric layer alignment critically determines overall conductivity.

Lastly, the high electrode-skin impedance characteristic of textile electrodes can create an impedance mismatch with the LiveAmp amplifier input, potentially causing signal attenuation and increased noise susceptibility. While the LiveAmp system specifies high input impedance suitable for dry electrodes, the extremely high impedance of textile electrodes may approach levels where impedance matching becomes suboptimal. This mismatch represents a fundamental limitation addressable only through dedicated pre-amplifier design with ultra-high input impedance, motivating the next phase of hardware development described in the future work section.

# 4.0 Future Work

Firstly, the PSD analysis conducted to date has focused on singular comparisons and therefore, a comprehensive analysis and average of all nine textile electrode configurations across the complete frequency spectrum remains to be completed. This systematic PSD analysis will enable detailed quantification of how each design parameter (raised height, silver density, electrode area) influences spectral characteristics across clinically relevant EEG frequency bands including delta (0.5-4 Hz), theta (4-8 Hz), alpha (8-13 Hz), and beta (13-30 Hz). Additionally, future work on the data analysis side includes improving figure presentation by standardizing axis scaling and refining legends and titles for greater clarity and consistency.

The primary focus for the Winter 2026 term centers on designing and prototyping an active electrode pre-amplifier system specifically optimized for textile electrode characteristics. This pre-amplifier will implement a three-stage instrumentation amplifier topology providing ultra-high input impedance, configurable gain, and appropriate frequency filtering. High input impedance will be achieved through bootstrapping techniques and careful selection of ultra-low bias current operational amplifiers.

Configurability represents a key design requirement enabling optimization for different measurement sites and electrode types. Gain will be adjustable through surface-mount device (SMD) resistor selection, allowing tailored amplification for the varying signal amplitudes encountered across scalp locations. Similarly, band-pass filtering characteristics will be configurable via SMD resistors, enabling adjustment of high-pass and low-pass cutoff frequencies to match specific application requirements while maximizing signal-to-noise ratio.

Common-mode noise rejection will be addressed through differential amplifier design with high common-mode rejection ratio and will operate from 3.3-5V supply rails to enable integration with portable battery-powered systems. The output of the pre-amplifier will interface directly with the Texas Instruments ADS1299x family of analog-to-digital converters, which provide 24-bit resolution and integrated programmable gain amplifiers specifically designed for EEG applications.

Component selection and initial circuit simulation are planned for completion by the end of January 2026, followed by a printed circuit board PCB layout and fabrication in early February. Prototype testing against wet electrode reference systems will commence in mid-February, with iterative refinement continuing through March 2026. Initial prototyping will utilize breadboards, and conventional PCBs, however, if time permits, flexible PCB (flex PCB) technology represents a promising future direction for integrating the pre-amplifier directly into textile electrode assemblies. Performance metrics including input impedance, noise floor, and frequency response will be characterized using signal generator validation before proceeding to human subject testing. The integration of an optimized pre-amplifier with textile electrodes and comprehensive benchmarking against clinical-grade systems will constitute the final validation phase, scheduled for mid-March 2026 to allow sufficient time for thesis writing and presentation in early April 2026.

# 5.0 References

[1] G. Acar et al., “Wearable and flexible textile electrodes for biopotential signal monitoring: A Review,” Electronics, vol. 8, no. 5, p. 479, Apr. 2019. doi:10.3390/electronics8050479

[2] C. M. Vidhya, Y. Maithani, and J. P. Singh, “Recent advances and challenges in textile electrodes for wearable biopotential signal monitoring: A comprehensive review,” Biosensors, vol. 13, no. 7, p. 679, Jun. 2023. doi:10.3390/bios13070679

[3] A. B. Nigusse, D. A. Mengistie, B. Malengier, G. B. Tseghai, and L. V. Langenhove, “Wearable smart textiles for long-term electrocardiography monitoring—a review,” Sensors, vol. 21, no. 12, p. 4174, Jun. 2021. doi:10.3390/s21124174

[4] Q. Liu et al., “The feature, performance, and prospect of advanced electrodes for electroencephalogram,” Biosensors, vol. 13, no. 1, p. 101, Jan. 2023. doi:10.3390/bios13010101

[5] J. Löfhede, F. Seoane, and M. Thordstein, “Textile electrodes for EEG recording — a pilot study,” Sensors, vol. 12, no. 12, pp. 16907–16919, Dec. 2012. doi:10.3390/s121216907

[6] J. Xu, S. Mitra, C. Van Hoof, R. F. Yazicioglu, and K. A. Makinwa, “Active electrodes for wearable EEG acquisition: Review and Electronics Design Methodology,” IEEE Reviews in Biomedical Engineering, vol. 10, pp. 187–198, 2017. doi:10.1109/rbme.2017.2656388

[7] R. R. Harrison and C. Charles, “A low-power low-noise CMOS for amplifier neural recording applications,” IEEE Journal of Solid-State Circuits, vol. 38, no. 6, pp. 958–965, Jun. 2003. doi:10.1109/jssc.2003.811979

[8] E. López-Larraz et al., “A garment that measures brain activity: Proof of concept of an EEG sensor layer fully implemented with Smart Textiles,” Frontiers in Human Neuroscience, vol. 17, May 2023. doi:10.3389/fnhum.2023.1135153

[9] S. M. Rahman, H. Mattila, M. Janka, and J. Virkki, “Impedance evaluation of textile electrodes for EEG measurements,” Textile Research Journal, vol. 93, no. 7–8, pp. 1878–1888, Nov. 2022. doi:10.1177/00405175221135131

[10] M. Chen, J. Wang, D. Anzai, G. Fischer, and J. Kirchner, “Common-mode noise reduction in noncontact biopotential acquisition circuit based on imbalance cancellation of electrode-body impedance,” Sensors, vol. 20, no. 24, p. 7140, Dec. 2020. doi:10.3390/s20247140

[11] Y. M. Chi, C. Maier, and G. Cauwenberghs, “Integrated ultra-high impedance front-end for non-contact biopotential sensing,” 2011 IEEE Biomedical Circuits and Systems Conference (BioCAS), pp. 456–459, Nov. 2011. doi:10.1109/biocas.2011.6107826

[12] M. A. Mayosky and E. M. Spinelli, “AC coupled three op-amp biopotential amplifier with active DC suppression,” IEEE Transactions on Biomedical Engineering, vol. 47, no. 12, pp. 1616–1619, 2000. doi:10.1109/10.887943

[13] R. Pallás-Areny and J. G. Webster, “Composite instrumentation amplifier for biopotentials,” Annals of Biomedical Engineering, vol. 18, no. 3, pp. 251–262, May 1990. doi:10.1007/bf02368441

[14] S. Vanhatalo, J. Voipio, and K. Kaila, “Full-band EEG (FBEEG): An emerging standard in electroencephalography,” Clinical Neurophysiology, vol. 116, no. 1, pp. 1–8, Jan. 2005. doi:10.1016/j.clinph.2004.09.015

# 6.0 Appendix

The following section provides more detailed images on the progress made in various areas.

# 6.1 Appendix A: Textile Electrode Images

Figures 8-10 shows the close-ups of all the raised height electrodes.

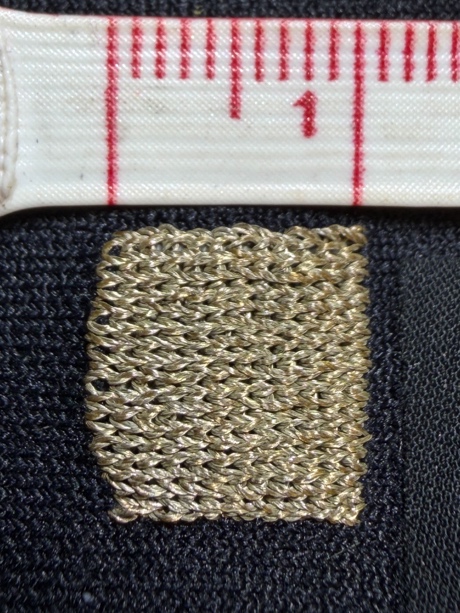
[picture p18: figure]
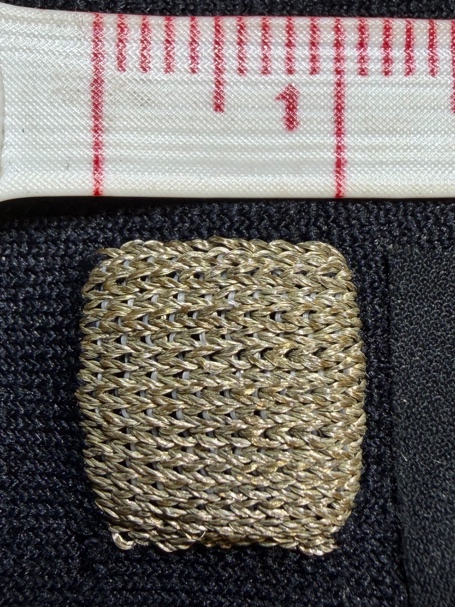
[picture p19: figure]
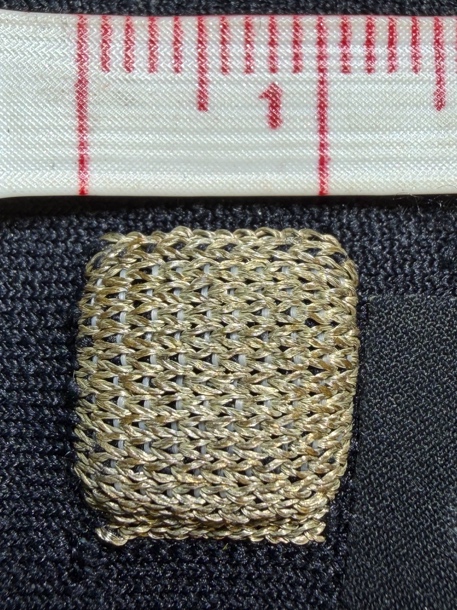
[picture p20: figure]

Figure 8. Close up of Electrode 1.1. | Figure 9. Close up of Electrode 1.2. | Figure 10. Close up of Electrode 1.3.

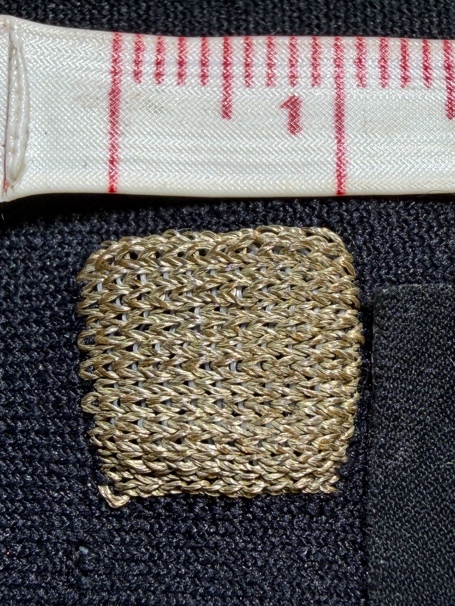
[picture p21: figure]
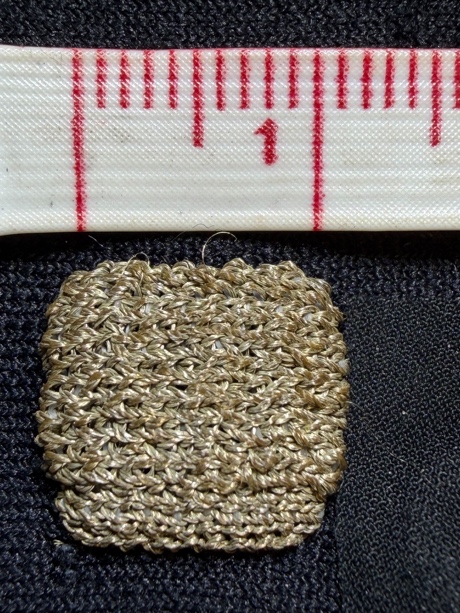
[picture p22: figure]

Figure 11. Close up of Electrode 2.1. | Figure 12. Close up of Electrode 2.2. | Figure 13. Close up of Electrode 3.2

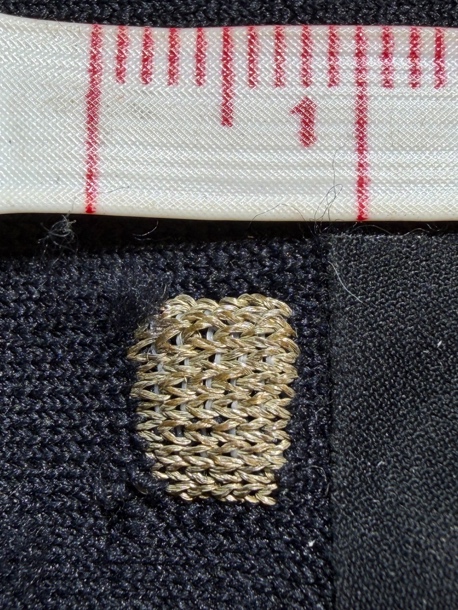
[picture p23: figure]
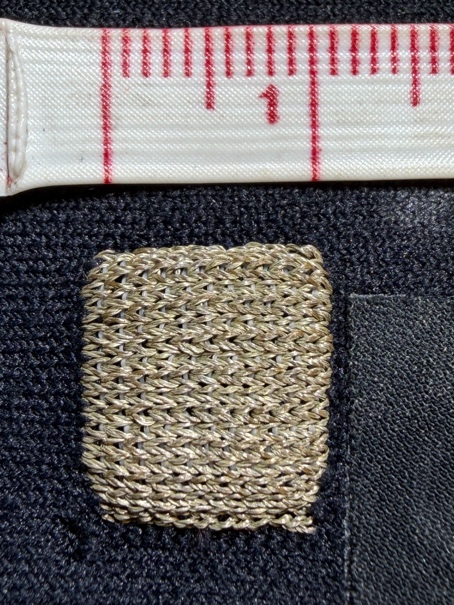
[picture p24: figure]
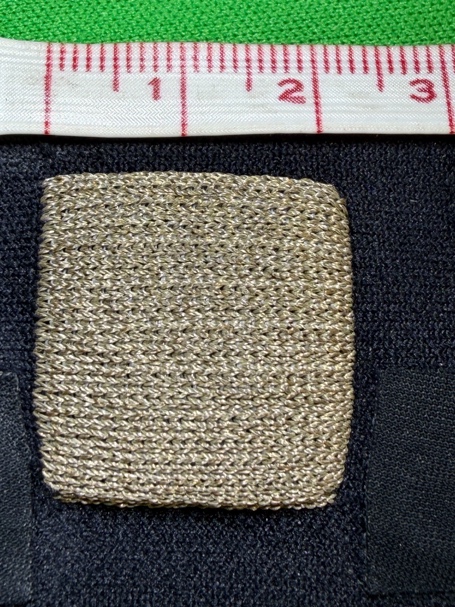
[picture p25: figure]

Figure 14. Close up of Electrode 3.1. | Figure 15. Close up of Electrode 3.2. | Figure 16. Close up of Electrode 3.3.

# 6.2 Appendix B: Blink Epoch Data Analysis

Full blink epoch analysis for all nine textile electrodes shown in Figures 17-25.


Figure 17. Detailed blink epoch analysis for Electrode 1.1.


Figure 18. Detailed blink epoch analysis for Electrode 1.2.


Figure 19. Detailed blink epoch analysis for Electrode 1.3.


Figure 20. Detailed blink epoch analysis for Electrode 2.1.


Figure 21. Detailed blink epoch analysis for Electrode 2.2.


Figure 22. Detailed blink epoch analysis for Electrode 2.3.


Figure 23. Detailed blink epoch analysis for Electrode 3.1.


Figure 24. Detailed blink epoch analysis for Electrode 3.2.


Figure 25. Detailed blink epoch analysis for Electrode 3.3.

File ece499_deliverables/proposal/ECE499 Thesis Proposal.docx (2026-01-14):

Development and Characterization of Textile-Electrode Electroencephalogram Systems for Brain-Computer Interfaces

Conventional electroencephalogram (EEG) systems rely on wet electrodes that require conductive gel, which limits comfort and mobility, however, in recent years, there is growing interest in developing wearable EEG collection devices. Textile-based electrodes have emerged as a promising alternative for wearable EEG systems as they offer both improved comfort, flexibility in use case, and simple integration into fabric for brain-computer interface (BCI) applications [1], [2]. However, a significant challenge posed by these textile-based electrodes is achieving high signal quality comparable to clinical and research grade electrodes due to high impedance across skin and hair connections [1], [3].

The objective of this study is to advance the development of a wearable EEG system using textile-based electrodes for signal acquisition over hair-covered regions and regions where the skin is exposed directly. The project encompasses both hardware and software development, with a focus on prototyping pre-amplifier circuits for textile electrodes and designing computational methods for processing these recorded textile-based EEG signals. An optimized pre-amplifier circuit design and tailored digital signal processing algorithms should greatly improve the signal-to-noise ratio and classification accuracy of textile-based EEG readings, making them comparable to standard clinical and research grade systems.

This project approach follows the iterative design and evaluation of a wearable EEG system using textile-based electrodes with a pre-amplifier circuit that will be prototyped with various hardware filters such as a low-pass filter or unity gain to optimize signals acquired from textile electrodes, following principles established in biopotential amplifier designs which produces low electrical interference [4], [5]. Measurements will be made for input impedance, common-mode rejection ratio, and baseline noise using a signal generator while EEG data will also be digitally filtered through signal processing techniques including adaptive filtering and independent component analysis (ICA) to remove any artifacts [1], [6].

The pre-amplifier circuit will be tested to specifically improve signal acquisition from textile electrodes by maximizing its input impedance and minimizing noise with off-the-shelf components. Afterwards, digital signal processing methods including adaptive filtering and ICA will be implemented to enhance textile-based EEG signals. Models will be developed to mitigate noise, improve signal-to-noise ratio, and optimize classification performance in BCI applications. The combined hardware and software system’s performance will be characterized and benchmarked against gold-standard clinical EEG electrodes in both simple experimental paradigms such as eyes-open/eyes-closed and established BCI tasks from both hair-covered and bare-skin regions of the head.

This research aims to demonstrate the technical feasibility of textile-based EEG for wearable BCI applications, and its research outcomes are expected to contribute both to academic knowledge and to potential commercialization efforts in collaboration with industry partners. Findings will support the preparation of a publication detailing textile electrode validation, EEG signal pre-amplifier design, and software-based signal filtering, with future applications extending toward wearable BCI systems and clinical use cases.

References

[1] G. Acar et al., “Wearable and flexible textile electrodes for biopotential signal monitoring: A Review,” Electronics, vol. 8, no. 5, p. 479, Apr. 2019. doi:10.3390/electronics8050479

[2] L. Euler, L. Guo, and N.-K. Persson, “A review of textile-based electrodes developed for electrostimulation,” Textile Research Journal, vol. 92, no. 7–8, pp. 1300–1320, Oct. 2021. doi:10.1177/00405175211051949

[3] E. López-Larraz et al., “A garment that measures brain activity: Proof of concept of an EEG sensor layer fully implemented with Smart Textiles,” Frontiers in Human Neuroscience, vol. 17, May 2023. doi:10.3389/fnhum.2023.1135153

[4] E. Huigen, A. Peper, and C. A. Grimbergen, “Investigation into the origin of the noise of surface electrodes,” Medical and Biological Engineering and Computing, vol. 40, no. 3, pp. 332–338, May 2002. doi:10.1007/bf02344216

[5] B. B. Winter and J. G. Webster, “Reduction of interference due to common mode voltage in biopotential amplifiers,” IEEE Transactions on Biomedical Engineering, vol. BME-30, no. 1, pp. 58–62, Jan. 1983. doi:10.1109/tbme.1983.325167

[6] D. Seok, S. Lee, M. Kim, J. Cho, and C. Kim, “Motion artifact removal techniques for wearable EEG and PPG Sensor Systems,” Frontiers in Electronics, vol. 2, May 2021. doi:10.3389/felec.2021.685513

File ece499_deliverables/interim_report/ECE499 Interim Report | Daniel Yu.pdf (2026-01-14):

Development and Characterization of Textile-Electrode Electroencephalogram Systems for Brain-Computer Interfaces

Daniel Yu
1007678461
January 12th, 2026

Supervisors: Dr. Tom Chau, Dr. Paul Yoo
ECE499Y Thesis | Interim Report

Table of Contents

List of Figures

Figure 1. Three fabric headbands with two textile electrodes of each configuration sewn onto it,

Figure 2. Raw EEG recording from the 30-45 second window for Electrode 1.1 (raised height of

Figure 3. Event related potentials and average amplitude in microvolts for all recorded blinks

Figure 4. Percent difference on the measured microvolts across all nine textile electrodes........ 12

Figure 6. PSD plot showing higher Alpha band activity during eyes closed experiments on

Figure 7. PSD plot showing lower Alpha band activity during eyes open experiments on

List of Tables
Table 1. All nine tested textile electrode configurations following the order shown in Figure 1. . 8

### 1.0 Introduction

Electroencephalogram (EEG) systems have become essential tools in both clinical diagnostics and research application, particularly in the field of brain-computer interfaces (BCIs). Conventional EEG systems rely on wet electrodes that require conductive gel to establish electrical contact between the scalp and sensing hardware. While these systems deliver high signal quality suitable for various clinical and research purposes, they present practical limitation as its application of conductive gel is time-consuming, uncomfortable for users, and may cause skin irritation when worn for extended periods. These constraints make traditional wet electrode systems impractical for pediatric population in rehab and long-duration monitoring clinical or research cases.

In recent years, there has been growing interest in developing wearable EEG collection devices that address these usability challenges. Textile-based electrodes have emerged as a promising alternative as its simple integration into fabrics offers improved comfort and flexibility. Unlike wet electrodes, textile electrodes can be incorporated directly into wearable garments or headbands in a dry format without the need for conductive gel. This technological shift has the potential to expand EEG accessibility beyond traditional clinical settings into community and home environments. However, a significant technical challenge persists as textile-based electrodes have not yet proven to achieve signal quality comparable to clinical and researchgrade wet electrodes. The primary limitation stems from high impedance at the electrode-skin interface, particularly over hair-covered regions of the scalp where establishing consistent electrical contact is inherently difficult. This impedance mismatch introduces increased noise, reduced signal amplitude, and greater susceptibility to motion artifacts, all of which compromise the reliability of recorded EEG signals. For textile electrodes to become viable alternatives in clinical and BCI applications, these signal quality limitations must be systematically addressed through coordinated advances in both hardware design and signal processing methodologies.

The objective of this thesis is to advance the development of a wearable EEG systems using textile-based electrodes for signal acquisition over both hair-covered regions and areas where skin is directly exposed. By addressing both the pre-amplifier circuit design and digital signal processing techniques, this research aims to maximize the signal-to-noise ratio and classification accuracy of textile-based EEG recordings, ultimately achieving performance comparable to standard clinical systems. The combined hardware-software system developed through this work will be characterized and benchmarked against gold-standard clinical EEG electrodes using both motion artifacts detection and fundamental experimental paradigms (such as eyes-open/eyes-closed protocols). Performance will be evaluated across measurement sites on both hair-covered and bare-skin regions to comprehensively assess the system's practical applicability.

The significance of this research extends beyond immediate technical contributions as demonstrating the feasibility of textile-based EEG for wearable BCI applications addresses a critical gap in pediatric neurotechnology that conventional wet electrode systems cannot. Success in this work would enable more accessible, comfortable, and practical EEG monitoring solutions for children, supporting both clinical care delivery and research participation. Furthermore, the research outcomes are expected to contribute to both academic knowledge through publications and potential commercialization efforts with industry partners. Finally, the findings will support the preparation of manuscripts detailing textile electrode validation, EEG signal pre-amplifier design, and software-based signal filtering techniques, with applications extending toward nextgeneration wearable BCI systems and expanded clinical use cases in pediatric populations.

### 2.0 Literature Review

The development of textile-based electrodes for biopotential signal monitoring has emerged as a promising research direction in wearable health monitoring systems. Several groups have conducted comprehensive reviews demonstrating that textile electrodes can achieve acceptable signal quality for various biopotential measurements when properly designed and implemented [1, 2, 3]. Research comparing textile electrodes to standard clinical electrodes has yielded promising but varied results depending on measurement location and electrode design. Liu et al. investigated textile dry contact electrodes during physical activity, finding that correlation between EEG signals from wet and textile electrodes reached 95.6% under motion conditions, demonstrating near-equivalent signal capture capability [4]. However, textile electrodes face particular challenges when measuring over hair-covered regions of the scalp as studies have consistently shown that hair-covered areas present significantly higher impedance, reducing signal quality compared to hairless regions such as the forehead [4, 5].

Additionally, the amplification of biopotential signals presents unique technical challenges that distinguish these systems from general-purpose amplifiers. Biopotential amplifiers must satisfy several critical requirements such as the need for ultra-high input impedance to minimize signal loading, high common-mode rejection ratio (CMRR) to suppress noise, appropriate bandwidth for the signals of interest, sufficient gain to amplify microvolt-level signals, and protection circuits to ensure patient safety [6, 7].

The impedance characteristics of textile electrodes differ substantially from wet electrodes. López-Larraz et al. noted that while standard wet EEG electrodes typically exhibit impedances below 5 kΩ, textile and other dry sensors operate in the range of hundreds of kΩ, resulting in inherently higher noise levels [8]. This fundamental impedance difference necessitates specialized amplifier designs with ultra-high input impedance to prevent signal loading and distortion [6]. Rahman et al. demonstrated that skin impedance should ideally be maintained between 5-20 kΩ for accurate EEG signal generation, though this target becomes challenging to achieve with dry textile electrodes, particularly under dry skin conditions [9].

CMRR is equally critical for EEG amplifier design as it quantifies an amplifier's ability to reject signals common to both inputs while amplifying differential signals. This is an essential capability given that EEG signals, typically measured in microvolts are mixed with larger common-mode interference from sources such as power line coupling and muscle artifacts [10]. High-performance instrumentation amplifiers for biopotential measurement typically achieve CMRR values exceeding 110 dB across the frequency range of interest [11]. The three-amplifier instrumentation amplifier topology has become standard in biopotential applications, providing both high input impedance through buffer amplifiers and excellent CMRR through differential amplification stages [12, 13].

EEG signals span from approximately 0.5 Hz to 100 Hz, with most clinically relevant information contained below 40 Hz [14]. This means that bandwidth and filtering requirements must be carefully matched to the EEG frequency content of interest as limiting bandwidth to this range not only preserves signal fidelity but also optimizes signal-to-noise ratio by rejecting outof-band interference. Typical implementations include high-pass filters above 0.5 Hz to remove DC offset and electrode polarization effects, and low-pass filters below 100 Hz to prevent aliasing and reduce high-frequency noise [14]. The transition between passband and stopband must be sufficiently gradual to avoid phase distortion that could compromise temporal relationships in the signal.

Altogether, active electrode designs where amplification occurs immediately at the electrode site, have gained prominence in dry electrode EEG systems [6]. This approach offers multiple advantages as the amplified signal is less susceptible to cable motion artifacts, the ultra-high input impedance at the electrode prevents impedance mismatch effects, and the low output impedance of the active electrode drives subsequent amplification stages efficiently [6].

### 3.0 Progress to Date

Building upon the theoretical foundation establish in the literature review, the initial phase of this work constituted experimental data collection and characterization of textile-based electrode signal quality from September to December 2025. This part of the research aimed to establish baseline performance metrics for various textile electrode design parameter and validate their signal quality against gold-standard clinical EEG systems.

### 3.1 Data Collection

The experimental protocol was designed to systematically evaluate textile electrode performance across multiple design parameters while maintaining controlled comparison with established dry electrode technology. Nine types of textile electrodes that were sewn onto three fabric headbands were tested with each headband varying across three primary design dimensions described in the Table 1 and shown in the same order in Figure 1. All textile electrodes are approximately 1.0 cm x 1.0 cm if not specified. More detailed images of can be seen in Appendix A.

Table 1. All nine tested textile electrode configurations following the order shown in Figure 1.
Raised Height | Electrode 1.1 1 mm | Electrode 1.2 2 mm | Electrode 1.3 3 mm
Silver Density | Electrode 2.1 Least dense (1.0x) | Electrode 2.2 Moderately dense (1.5x) | Electrode 2.3 Most dense (2.0x)
Area Size | Electrode 3.1 0.5 cm x 0.5 cm | Electrode 3.2 2.0 cm x 2.0 cm | Electrode 3.3 1.0 cm x 1.0 cm


Figure 1. Three fabric headbands with two textile electrodes of each configuration sewn onto it, totalling 18 total textile electrodes.

The data acquisition utilized the BrainProducts LiveAmp system in conjunction with Lab Recorder and Mindset software, enabling synchronized multichannel EEG recording with precise timing control. The experimental setup positioned textile electrodes at Fp1 and the gold-standard clinical BrainProducts electrodes without the use of gel at the Fp2 location according to the international 10-20 system. Both electrodes used the BrainProducts pre-amplifier circuit connected by a snap button with ground and reference electrodes placed beside each other behind the left ear. The forehead placement was strategically chosen as it represents a hairless region with relatively low impedance, allowing initial validation of textile electrode performance under favorable conditions before progressing to more challenging hair-covered sites.

Two complementary experiments were implemented to assess different aspects of electrode performance. The blink test protocol required me to perform deliberate eye blinks at approximately two-second intervals over a 200-second recording session for each of the nine electrode configurations. This test specifically targets motion artifact characterization, as eye blinks generate large-amplitude, artifacts propagating across frontal electrodes. The consistent morphology and timing of blink artifacts provides a quantifiable metric for comparing artifact amplitude, waveform fidelity, and signal-to-noise characteristics between textile and commercial electrodes.

The second experiment was a eyes-open/eyes-closed test that assessed the electrodes' ability to capture physiologically relevant neural oscillations, specifically focusing on alpha band (8-13 Hz) modulation. This protocol required me to alternate between 10-second eyes-open and 10-second eyes-closed recordings, repeated ten times per electrode configuration. Alpha synchronization during eyes closure from a reduced visual processing demand and cortical idling provides a strong benchmark for evaluating electrode sensitivity to frequency-specific neural activity.

### 3.2 Data Analysis

Preliminary analysis of blink-induced motion artifacts revealed clear, systematic differences between textile and commercial dry EEG electrodes, driven primarily by electrode–skin contact mechanics. Blink artifacts appeared as large, bilaterally symmetric deflections in both Fp1 and Fp2 as seen in Figure 2, often reaching several hundred microvolts, making them a sensitive indicator of contact quality and impedance.


Figure 2. Raw EEG recording from the 30-45 second window for Electrode 1.1 (raised height of 1 mm).

Figure 3 show the exact difference between textile electrodes and the gold-standard ones on event-related potentials across all blinks. This figure shows the performance of Electrode 1.1 (raised height of 1 mm) on the Fp1 position shown in blue compared against the performance of the gold-standard electrode shown in orange at Fp2. At the average peak amplitude, there is approximately an 11.5% percent difference, or around 41.4 µV between their detection peaks on average.


Figure 3. Event related potentials and average amplitude in microvolts for all recorded blinks during the recording of Electrode 1.1 (raised height of 1 mm).

Within the textile designs, electrode height had the strongest effect as 2–3 mm raised electrodes produced artifact amplitudes and temporal profiles closely matching those of the gold-standard dry electrodes, whereas 1 mm electrodes showed attenuated responses, consistent with inadequate contact pressure during facial muscle motion. These observations support the general expectations that increased electrode height improves penetration through superficial skin layers and stabilizes the interface. Higher silver density reduced baseline noise and improved stability between blink events, though its impact on artifact amplitude was weaker than that of height, indicating that mechanical contact dominates artifact formation. Electrode area affected both amplitude and drift: larger areas captured stronger blink artifacts but were more prone to baseline instability, while a 1.0 cm area offered a practical compromise. Full event related potential analysis can be seen in Appendix B.

Overall, this is summarized in Figure 4 as a percent difference of the microvolts detected between the current tested textile electrode and the gold-standard one. Furthermore, the signalto-noise ratio (SNR) was calculated and summarized in Figure 5, by comparing root mean square of the overall signal strength against the high-frequency noise levels above 30 Hz for each textile electrode, and its results match the percent difference in Figure 4 in a nearly inversely proportional manner.


Figure 4. Percent difference on the measured microvolts across all nine textile electrodes.


Figure 5. Signal-to-noise ratio on across all nine textile electrodes.

For the eyes-open/eyes-closed experiment, initial power spectral density (PSD) analysis showed that textile electrodes reliably captured physiologically meaningful alpha activity, with increased 8–13 Hz power during eyes-closed conditions across all configurations as seen in comparison of Figure 6 and 7. While textile electrodes reproduced correct alpha peak frequencies and temporal modulation, they exhibited broader spectra, slightly slower transition dynamics, and lower correlations with the gold-standard electrodes, indicating a slightly reduced but still robust fidelity in detecting neural oscillations.


Figure 6. PSD plot showing higher Alpha | Figure 7. PSD plot showing lower Alpha
band activity during eyes closed experiments | band activity during eyes open experiments
on Electrode 1.1 (raised height of 1 mm). | on Electrode 1.1 (raised height of 1 mm)

### 3.4 Limitations

Several experimental limitations must be acknowledged in the interpretations and characterization of the results. The method in which the textile electrode were attached lacked precise control over contact pressure, as textile electrodes were manually positioned and secured with fabric headbands rather than standardized fixtures. Variations in headband tension across trials likely introduced inconsistencies in electrode-skin contact pressure, potentially contributing to performance variability beyond inherent electrode design differences. This limitation particularly affects interpretation of raised height comparisons, where contact pressure directly influences effective skin penetration depth.

Manufacturing variability in the sewn textile electrode patches represents another source of uncertainty. Minor variations in thread tension, stitch density, and conductive material distribution may result in inconsistencies that partially obscure the different design parameter effects, particularly for the silver density variations where fabric layer alignment critically determines overall conductivity.

Lastly, the high electrode-skin impedance characteristic of textile electrodes can create an impedance mismatch with the LiveAmp amplifier input, potentially causing signal attenuation and increased noise susceptibility. While the LiveAmp system specifies high input impedance suitable for dry electrodes, the extremely high impedance of textile electrodes may approach levels where impedance matching becomes suboptimal. This mismatch represents a fundamental limitation addressable only through dedicated pre-amplifier design with ultra-high input impedance, motivating the next phase of hardware development described in the future work section.

### 4.0 Future Work

Firstly, the PSD analysis conducted to date has focused on singular comparisons and therefore, a comprehensive analysis and average of all nine textile electrode configurations across the complete frequency spectrum remains to be completed. This systematic PSD analysis will enable detailed quantification of how each design parameter (raised height, silver density, electrode area) influences spectral characteristics across clinically relevant EEG frequency bands including delta (0.5-4 Hz), theta (4-8 Hz), alpha (8-13 Hz), and beta (13-30 Hz). Additionally, future work on the data analysis side includes improving figure presentation by standardizing axis scaling and refining legends and titles for greater clarity and consistency.

The primary focus for the Winter 2026 term centers on designing and prototyping an active electrode pre-amplifier system specifically optimized for textile electrode characteristics. This pre-amplifier will implement a three-stage instrumentation amplifier topology providing ultra-high input impedance, configurable gain, and appropriate frequency filtering. High input impedance will be achieved through bootstrapping techniques and careful selection of ultra-low bias current operational amplifiers.

Configurability represents a key design requirement enabling optimization for different measurement sites and electrode types. Gain will be adjustable through surface-mount device (SMD) resistor selection, allowing tailored amplification for the varying signal amplitudes encountered across scalp locations. Similarly, band-pass filtering characteristics will be configurable via SMD resistors, enabling adjustment of high-pass and low-pass cutoff frequencies to match specific application requirements while maximizing signal-to-noise ratio. Common-mode noise rejection will be addressed through differential amplifier design with high common-mode rejection ratio and will operate from 3.3-5V supply rails to enable integration with portable battery-powered systems. The output of the pre-amplifier will interface directly with the Texas Instruments ADS1299x family of analog-to-digital converters, which provide 24-bit resolution and integrated programmable gain amplifiers specifically designed for EEG applications.

Component selection and initial circuit simulation are planned for completion by the end of January 2026, followed by a printed circuit board PCB layout and fabrication in early February. Prototype testing against wet electrode reference systems will commence in mid-February, with iterative refinement continuing through March 2026. Initial prototyping will utilize breadboards, and conventional PCBs, however, if time permits, flexible PCB (flex PCB) technology represents a promising future direction for integrating the pre-amplifier directly into textile electrode assemblies. Performance metrics including input impedance, noise floor, and frequency response will be characterized using signal generator validation before proceeding to human subject testing. The integration of an optimized pre-amplifier with textile electrodes and comprehensive benchmarking against clinical-grade systems will constitute the final validation phase, scheduled for mid-March 2026 to allow sufficient time for thesis writing and presentation in early April 2026.

### 5.0 References

[1] G. Acar et al., “Wearable and flexible textile electrodes for biopotential signal monitoring: A Review,” Electronics, vol. 8, no. 5, p. 479, Apr. 2019. doi:10.3390/electronics8050479
[2] C. M. Vidhya, Y. Maithani, and J. P. Singh, “Recent advances and challenges in textile electrodes for wearable biopotential signal monitoring: A comprehensive review,” Biosensors, vol. 13, no. 7, p. 679, Jun. 2023. doi:10.3390/bios13070679
[3] A. B. Nigusse, D. A. Mengistie, B. Malengier, G. B. Tseghai, and L. V. Langenhove, “Wearable smart textiles for long-term electrocardiography monitoring—a review,” Sensors, vol. 21, no. 12, p. 4174, Jun. 2021. doi:10.3390/s21124174
[4] Q. Liu et al., “The feature, performance, and prospect of advanced electrodes for electroencephalogram,” Biosensors, vol. 13, no. 1, p. 101, Jan. 2023. doi:10.3390/bios13010101
[5] J. Löfhede, F. Seoane, and M. Thordstein, “Textile electrodes for EEG recording — a pilot study,” Sensors, vol. 12, no. 12, pp. 16907–16919, Dec. 2012. doi:10.3390/s121216907
[6] J. Xu, S. Mitra, C. Van Hoof, R. F. Yazicioglu, and K. A. Makinwa, “Active electrodes for wearable EEG acquisition: Review and Electronics Design Methodology,” IEEE Reviews in Biomedical Engineering, vol. 10, pp. 187–198, 2017. doi:10.1109/rbme.2017.2656388
[7] R. R. Harrison and C. Charles, “A low-power low-noise CMOS for amplifier neural recording applications,” IEEE Journal of Solid-State Circuits, vol. 38, no. 6, pp. 958–965, Jun. 2003. doi:10.1109/jssc.2003.811979
[8] E. López-Larraz et al., “A garment that measures brain activity: Proof of concept of an EEG sensor layer fully implemented with Smart Textiles,” Frontiers in Human Neuroscience, vol. 17, May 2023. doi:10.3389/fnhum.2023.1135153

[9] S. M. Rahman, H. Mattila, M. Janka, and J. Virkki, “Impedance evaluation of textile electrodes for EEG measurements,” Textile Research Journal, vol. 93, no. 7–8, pp. 1878– 1888, Nov. 2022. doi:10.1177/00405175221135131
[10] M. Chen, J. Wang, D. Anzai, G. Fischer, and J. Kirchner, “Common-mode noise reduction in noncontact biopotential acquisition circuit based on imbalance cancellation of electrodebody impedance,” Sensors, vol. 20, no. 24, p. 7140, Dec. 2020. doi:10.3390/s20247140
[11] Y. M. Chi, C. Maier, and G. Cauwenberghs, “Integrated ultra-high impedance front-end for non-contact biopotential sensing,” 2011 IEEE Biomedical Circuits and Systems Conference (BioCAS), pp. 456–459, Nov. 2011. doi:10.1109/biocas.2011.6107826
[12] M. A. Mayosky and E. M. Spinelli, “AC coupled three op-amp biopotential amplifier with active DC suppression,” IEEE Transactions on Biomedical Engineering, vol. 47, no. 12, pp. 1616–1619, 2000. doi:10.1109/10.887943
[13] R. Pallás-Areny and J. G. Webster, “Composite instrumentation amplifier for biopotentials,” Annals of Biomedical Engineering, vol. 18, no. 3, pp. 251–262, May 1990. doi:10.1007/bf02368441
[14] S. Vanhatalo, J. Voipio, and K. Kaila, “Full-band EEG (FBEEG): An emerging standard in electroencephalography,” Clinical Neurophysiology, vol. 116, no. 1, pp. 1–8, Jan. 2005. doi:10.1016/j.clinph.2004.09.015

### 6.0 Appendix

The following section provides more detailed images on the progress made in various areas.

### 6.1 Appendix A: Textile Electrode Images

Figures 8-10 shows the close-ups of all the raised height electrodes.


Figure 8. Close up of
Electrode 1.1.


Figure 9. Close up of
Electrode 1.2.


Figure 10. Close up of
Electrode 1.3.


Figure 11. Close up of
Electrode 2.1.

Figure 12. Close up of
Electrode 2.2.

Figure 13. Close up of
Electrode 3.2

Figure 14. Close up of
Electrode 3.1.

Figure 15. Close up of
Electrode 3.2.

Figure 16. Close up of
Electrode 3.3.

### 6.2 Appendix B: Blink Epoch Data Analysis

Full blink epoch analysis for all nine textile electrodes shown in Figures 17-25.


Figure 17. Detailed blink epoch analysis for Electrode 1.1.


Figure 18. Detailed blink epoch analysis for Electrode 1.2.


Figure 19. Detailed blink epoch analysis for Electrode 1.3.


Figure 20. Detailed blink epoch analysis for Electrode 2.1.


Figure 21. Detailed blink epoch analysis for Electrode 2.2.


Figure 22. Detailed blink epoch analysis for Electrode 2.3.


Figure 23. Detailed blink epoch analysis for Electrode 3.1.


Figure 24. Detailed blink epoch analysis for Electrode 3.2.


Figure 25. Detailed blink epoch analysis for Electrode 3.3.

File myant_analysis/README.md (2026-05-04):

# Comprehensive XDF EEG Analysis Tool – For Thesis (Daniel Yu)

This repository contains `thesis_plot_xdf.py`, a thesis-focused EEG analysis script for `.xdf` recordings. It loads XDF EEG streams with MNE, cuts and filters the signals, and exports plots for:

- 📊 PSD and frequency-band summaries
- 🧠 ICA component summaries
- 📈 Raw EEG segment views
- 👁️ Blink epoch / ERP analysis (--analysis blink)
- 🌊 Alpha band and attenuation analysis (--analysis alpha)

Please note that this script was made specifically for the needs of my thesis.

## What The Script Does

For each XDF file, the script:

1. Loads EEG (and marker stream if available) from `.xdf`
2. Extracts/normalizes channel data into MNE `RawArray`
3. Determines standard 10-20 location
4. Applies 1-50 Hz filtering
5. Computes shared PSD scaling across all files in a run
6. Generates and saves analysis figures into results folders

For blink mode and alpha mode, it also computes grouped metrics across files and generates summary bar charts.

## Plots Generated

Per-file outputs (created for all runs):

- `psd_summary_<timestamp>.png`
	- PSD curves, electrode map (if location available), band-power bars, channel stats
- `ica_summary_<timestamp>.png`
	- ICA topomaps, ICA time courses, component statistics
- `raw_eeg_<window>_<timestamp>.png`
	- Raw EEG segment (default 30-45s, default is full recording if 30-45s does not exist)
- `comprehensive_analysis_<timestamp>.png`
	- Full recording view, frequency-band power, variability metrics, SNR bars

Additional per-file outputs by mode:

- Blink mode (`--analysis blink`):
	- `blink_epoch_analysis_<timestamp>.png`
		- Blink ERP, individual blink overlays, amplitude distributions, inter-channel comparison
- Alpha mode (`--analysis alpha`):
	- `alpha_wave_analysis_<timestamp>.png`
		- Alpha spectrum (8-13 Hz), alpha-over-time, filtered alpha, envelope, stats
	- Single-file alpha runs also create:
		- `alpha_time_frequency_<timestamp>.png`

Cross-file summary outputs:

- Blink mode (multi-file):
	- `snr_all_files_sorted_<timestamp>.png`
	- `snr_all_files_fp[#]_<timestamp>.png`
	- `percent_diff_all_files_sorted_<timestamp>.png`
- Alpha mode (multi-file):
	- `alpha_attenuation_summary_<timestamp>.png`
	- `alpha_attenuation_by_channel_<timestamp>.png`

## Output Folder Structure

- No analysis flag: outputs go to `xdf_results/<xdf_basename>/`
- `--analysis blink`: outputs go to `blink_results/<xdf_basename>/`
- `--analysis alpha`:
	- single-file run: `alpha_results/<xdf_basename>/`
	- subfolder batch run: `alpha_results/<subfolder_name>/<xdf_basename>/`

## How To Run

Run from repository root.

### 1) Single file

```bash
python thesis_plot_xdf.py /path/to/file.xdf
python thesis_plot_xdf.py /path/to/file.xdf --analysis blink
python thesis_plot_xdf.py /path/to/file.xdf --analysis alpha
```

### 2) Folder of XDF files

```bash
python thesis_plot_xdf.py /path/to/folder
python thesis_plot_xdf.py /path/to/folder --analysis blink
```

### 3) Alpha grouped-folder mode

```bash
python thesis_plot_xdf.py /path/to/alpha_parent --analysis alpha
```

In this mode, the parent folder must contain subfolders such as `1.1_eyes_open` and `1.1_eyes_closed`, each containing `.xdf` files.

### 4) Interactive mode

```bash
python thesis_plot_xdf.py
```

Then enter a path when prompted.

## Required XDF Input Layout

### A) Single-file mode

Any valid `.xdf` file path.

### B) Standard folder mode (no alpha grouping)

```text
your_folder/
	file1.xdf
	file2.xdf
	...
```

### C) Alpha grouped folder mode (`--analysis alpha`)

```text
alpha_parent/
	1.1_eyes_open/
		run1.xdf
		run2.xdf
	1.1_eyes_closed/
		run1.xdf
		run2.xdf
	2.1_eyes_open/
		...
	2.1_eyes_closed/
		...
```

Notes:

- Alpha grouping logic depends on subfolder names containing `_eyes_open` or `_eyes_closed`.
- Swatch/group labels are derived from the part before that suffix (example: `1.1` from `1.1_eyes_open`).
- If no EEG stream exists in an XDF file, that file is skipped with an error.

## Python And Library Versions

This workspace environment used:

- Python `3.12.11`
- `mne==1.10.1`
- `numpy==2.3.3`
- `scipy==1.16.2`
- `matplotlib==3.10.6`
- `pyxdf==1.17.0`

To install dependencies in a fresh environment:

```bash
pip install -r requirements.txt
```

## Other Notes

- The script attempts microvolt-to-volt conversion automatically when values look unscaled.
- For batch blink runs, it trims 10 seconds from start/end before analysis. This is only the case when the user input is a folder.
- For batch alpha runs, it trims 5 seconds from the start. This is only the case when the user input is a folder.
- Some channel-specific calculations expect channels like `Fp1` and `Fp2`; files without these labels may still plot, but some comparative metrics can be skipped.

## Troubleshooting

- `No .xdf files found`:
	- Check that files use lowercase `.xdf` extension and are in the expected folder level.
- `No EEG stream found in XDF file`:
	- Verify stream metadata/type in the recording.
- Empty or missing summary plots in grouped modes:
	- Ensure both open and closed sets exist for each swatch key.

## Contact

- UofT Email: [danielz.yu@mail.utoronto.ca](mailto:danielz.yu@mail.utoronto.ca)
- Personal Email: [danielu6776@gmail.com](mailto:danielu6776@gmail.com)

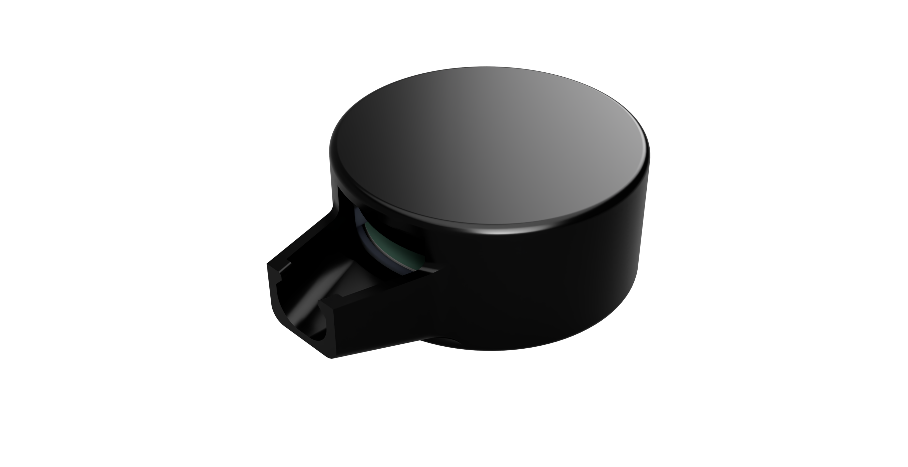
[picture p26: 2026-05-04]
enclosure_design_cad/renders/Electrode Enclosure Closed.png

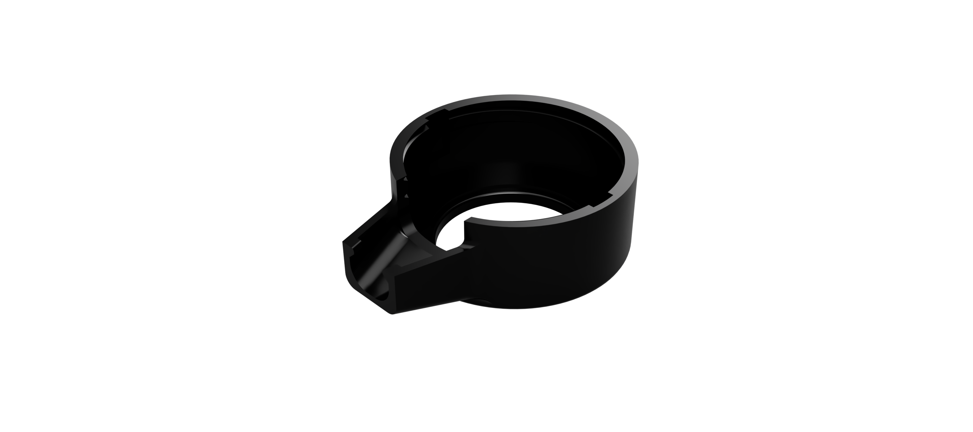
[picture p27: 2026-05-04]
enclosure_design_cad/renders/PCB Holder.png

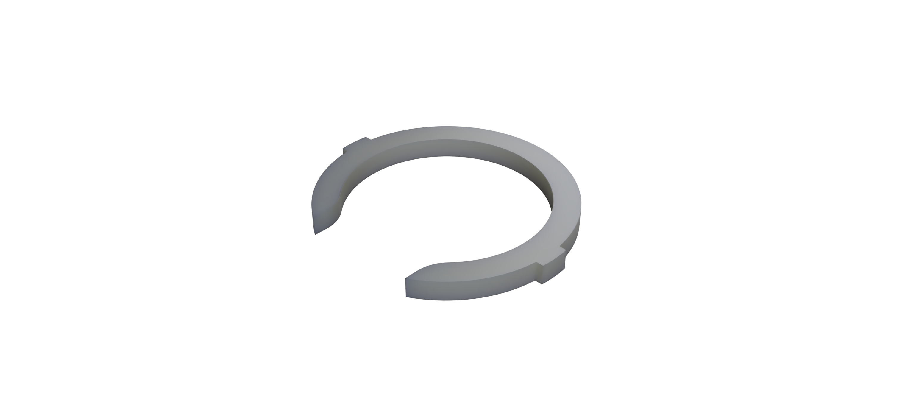
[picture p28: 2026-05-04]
enclosure_design_cad/renders/PCB Lock.png

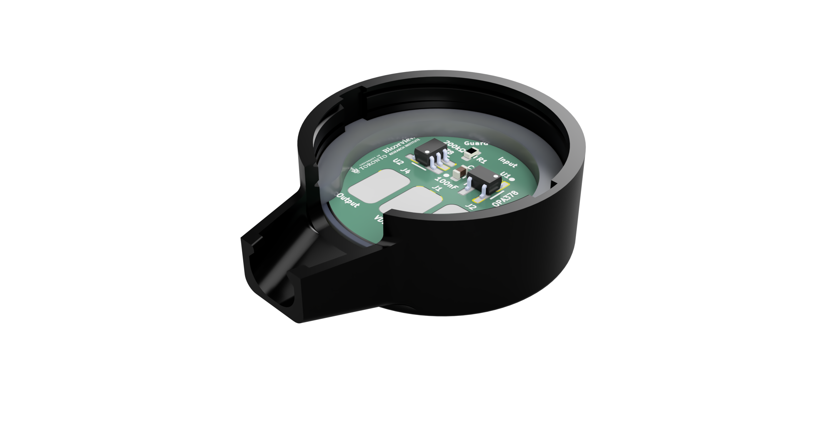
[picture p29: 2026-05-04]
enclosure_design_cad/renders/Electrode Enclosure Open.png

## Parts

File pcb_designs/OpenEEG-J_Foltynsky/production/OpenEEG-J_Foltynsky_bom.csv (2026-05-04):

Designator | Footprint | Quantity | Value | LCSC Part #
C1 | 0402 | 1 | 100nF
J1 | SolderWirePad | 1 | VDD
J2 | SolderWirePad | 1 | VSS
J3 | Snap_Button_Electrode | 1 | Input
J4 | SolderWirePad | 1 | Output
R1 | 0402 | 1 | 200kΩ
U1, U2 | SOT65P210X110-5N | 2 | OPA378

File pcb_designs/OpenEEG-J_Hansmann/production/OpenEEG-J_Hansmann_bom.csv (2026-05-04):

Designator | Footprint | Quantity | Value | LCSC Part #
C1 | 0402 | 1 | 10nF
C2, C3 | 0402 | 2 | 0.1nF
J1 | SolderWirePad | 1 | VDD
J2 | SolderWirePad | 1 | VSS
J3 | Snap_Button_Electrode | 1 | Input
J4 | SolderWirePad | 1 | Output
R1 | 0402 | 1 | 200kΩ
R2 | 0402 | 1 | 10kΩ
R3 | 0402 | 1 | 100Ω
U1 | SOT65P210X110-5N | 1 | OPA378

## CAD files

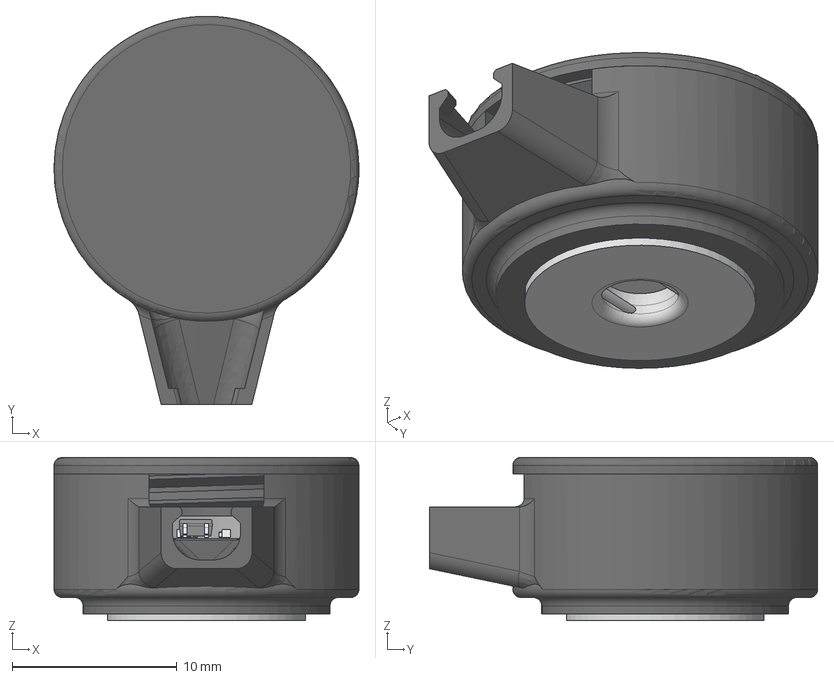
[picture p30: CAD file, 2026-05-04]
enclosure_design_cad/step/EEG Active Buffer Prototype 2 Assembly.step
18.5 x 23.6 x 9.90 mm
ECG Snap Button 4mm
PCB Soldering Holder
Electrode Case
PCB Lock
Electrode Case Cap
C_0402_1005Metric x 3
OPA378AIDCKR
R_0402_1005Metric x 3
OpenEEG-J_Hansmann_copper
OpenEEG-J_Hansmann_pad
OpenEEG-J_Hansmann_via
OpenEEG-J_Hansmann_silkscreen
OpenEEG-J_Hansmann_silkscreen_1
OpenEEG-J_Hansmann_soldermask
OpenEEG-J_Hansmann_soldermask_1
OpenEEG-J_Hansmann_PCB

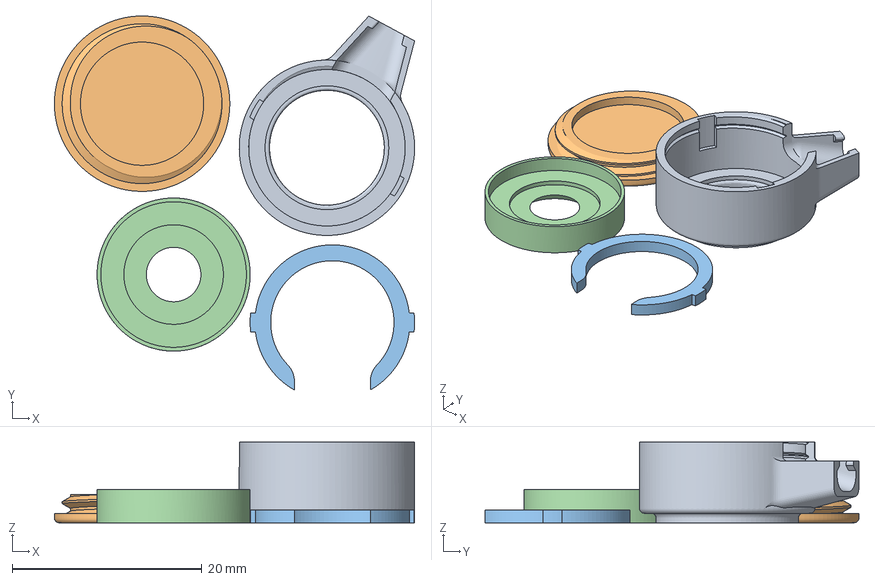
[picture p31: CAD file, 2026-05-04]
enclosure_design_cad/3D_printing/Electrode Case 3D Print File.3mf
38.0 x 39.4 x 8.50 mm
Electrode Case.stl
Electrode Case Cap.stl
PCB Lock.stl
PCB Soldering Holder.stl

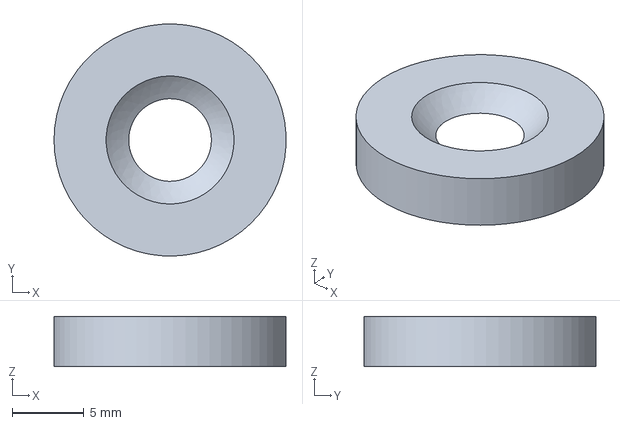
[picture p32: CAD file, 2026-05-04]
enclosure_design_cad/step/PCB Soldering Holder.step
16.1 x 16.1 x 3.50 mm

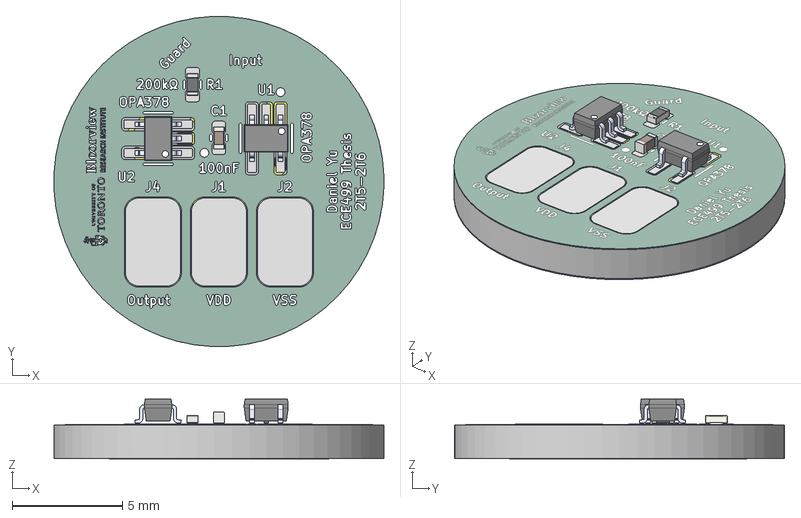
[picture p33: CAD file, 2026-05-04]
pcb_designs/OpenEEG-J_Foltynsky/OpenEEG-J_Foltynsky.step
15.0 x 15.0 x 2.77 mm
C_0402_1005Metric
OPA378AIDCKR x 2
R_0402_1005Metric
OpenEEG-J_Foltynsky_copper
OpenEEG-J_Foltynsky_pad
OpenEEG-J_Foltynsky_via
OpenEEG-J_Foltynsky_silkscreen x 2
OpenEEG-J_Foltynsky_soldermask x 2
OpenEEG-J_Foltynsky_PCB

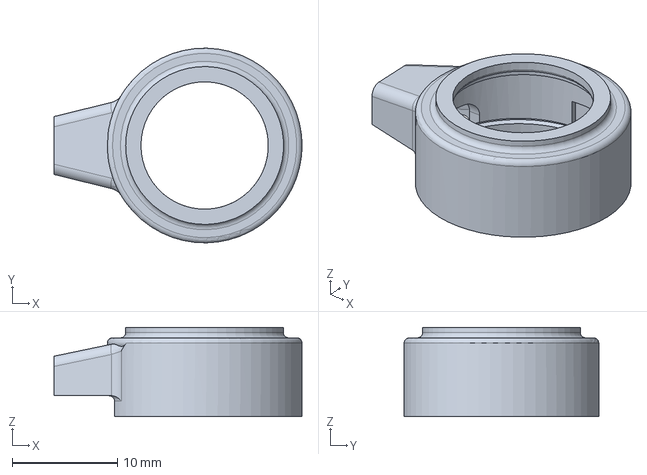
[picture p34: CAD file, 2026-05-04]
enclosure_design_cad/step/Electrode Case.step
23.6 x 18.5 x 8.50 mm

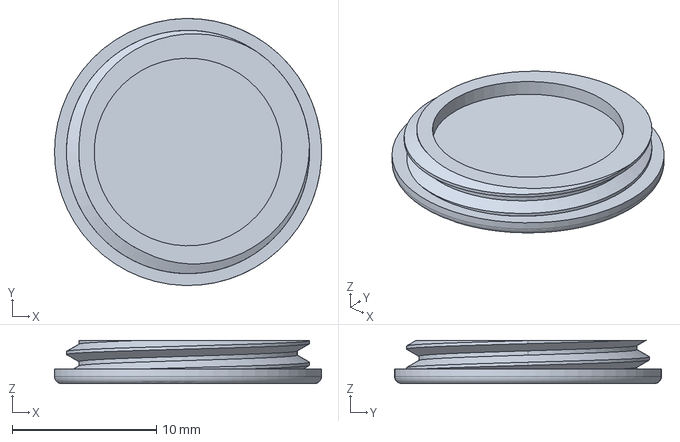
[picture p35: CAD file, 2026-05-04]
enclosure_design_cad/step/Electrode Case Cap.step
18.5 x 18.5 x 3.00 mm

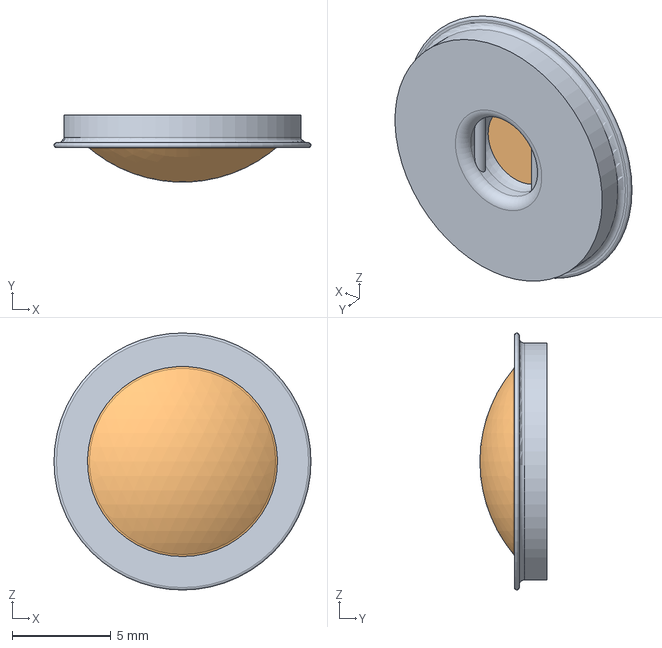
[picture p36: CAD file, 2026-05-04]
enclosure_design_cad/step/Snap Button.step
13.0 x 3.39 x 13.0 mm

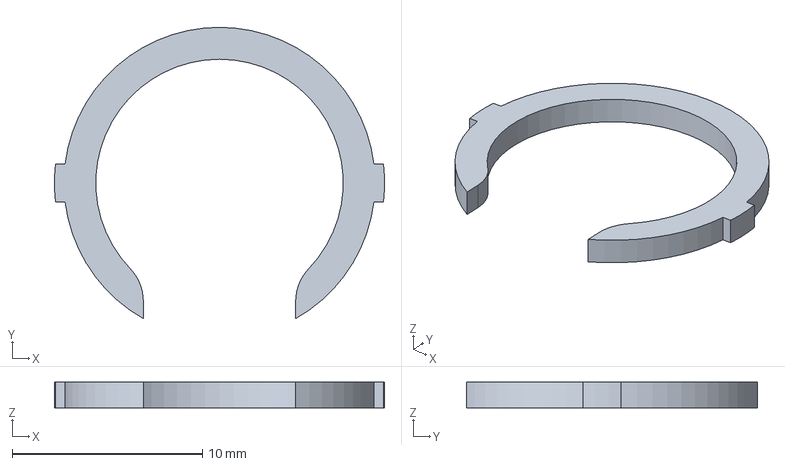
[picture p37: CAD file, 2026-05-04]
enclosure_design_cad/step/PCB Lock.step
17.3 x 15.3 x 1.35 mm

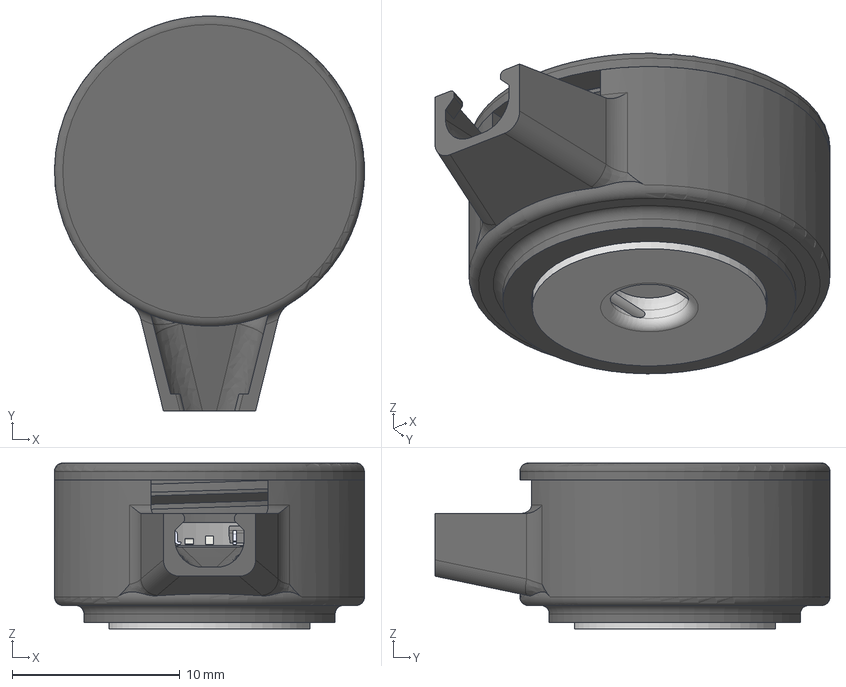
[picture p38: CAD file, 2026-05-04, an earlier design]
enclosure_design_cad/step/EEG Active Buffer Prototype 1 Assembly.step
18.5 x 23.6 x 9.90 mm
ECG Snap Button 4mm
Electrode Case
PCB Soldering Holder
Electrode Case Cap
PCB Lock
C_0402_1005Metric
OPA378AIDCKR x 2
R_0402_1005Metric
OpenEEG-J_Foltynsky_copper
OpenEEG-J_Foltynsky_pad
OpenEEG-J_Foltynsky_via
OpenEEG-J_Foltynsky_silkscreen
OpenEEG-J_Foltynsky_silkscreen_1
OpenEEG-J_Foltynsky_soldermask
OpenEEG-J_Foltynsky_soldermask_1
OpenEEG-J_Foltynsky_PCB

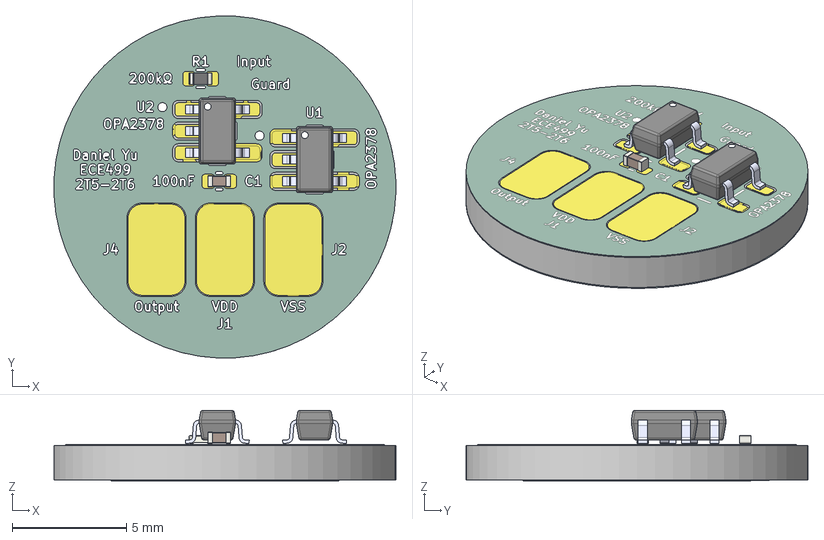
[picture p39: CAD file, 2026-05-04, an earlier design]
pcb_designs/old_designs/Incorrect_OpenEEG-J_Foltynsky/Incorrect_OpenEEG-J_Foltynsky.step
15.0 x 15.0 x 3.12 mm
OPA378AIDBVR x 2
R_0402_1005Metric
C_0402_1005Metric
OpenEEG-J_Foltynsky_copper
OpenEEG-J_Foltynsky_silkscreen x 2
OpenEEG-J_Foltynsky_soldermask x 2
OpenEEG-J_Foltynsky_PCB

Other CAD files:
pcb_designs/OpenEEG-J_Hansmann/OpenEEG-J_Hansmann.step
enclosure_design_cad/step/OpenEEG-J_Hansmann.step
enclosure_design_cad/step/OpenEEG-J_Foltynsky.step
pcb_designs/old_designs/Incorrect_OpenEEG-J_Hansmann/Incorrect_OpenEEG-J_Hansmann.step
enclosure_design_cad/fusion360/EEG Active Buffer Prototype 1 Assembly.f3z
enclosure_design_cad/fusion360/EEG Active Buffer Prototype 2 Assembly.f3z
enclosure_design_cad/fusion360/Electrode Case Cap.f3d
enclosure_design_cad/fusion360/Electrode Case.f3d
enclosure_design_cad/fusion360/OpenEEG-J_Foltynsky.f3d
enclosure_design_cad/fusion360/OpenEEG-J_Hansmann.f3d
enclosure_design_cad/fusion360/PCB Lock.f3d
enclosure_design_cad/fusion360/PCB Soldering Holder.f3d
enclosure_design_cad/fusion360/Snap Button.f3d
enclosure_design_cad/stl/Electrode Case Cap.stl
enclosure_design_cad/stl/Electrode Case.stl
enclosure_design_cad/stl/PCB Lock.stl
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

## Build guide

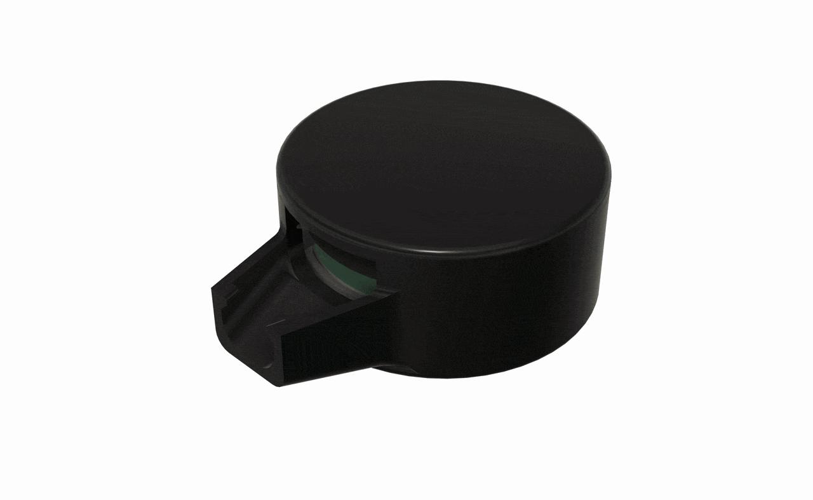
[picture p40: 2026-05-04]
enclosure_design_cad/renders/Exploded Assembly View.gif

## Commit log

2026-01-14 Updating myant_analysis repo and ECE499 deliverables from 2025
    [participants.tsv, sub-P001_ses-S001_scans.tsv, sub-P001_ses-S001_space-CapTrak_electrodes.tsv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]
2026-05-04 Removing large files from git tree
    [participants.tsv, sub-P001_ses-S001_scans.tsv, sub-P001_ses-S001_space-CapTrak_electrodes.tsv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]
2026-05-04 PCB designs
    [Incorrect_OpenEEG-J_Foltynsky.kicad_pcb, Incorrect_OpenEEG-J_Foltynsky.kicad_sch, Incorrect_OpenEEG-J_Foltynsky.step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]
2026-05-04 PCB enclosure CAD models
    [EEG Active Buffer Prototype 1 Assembly.f3z, EEG Active Buffer Prototype 1 Assembly.step, EEG Active Buffer Prototype 2 Assembly.f3z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]
